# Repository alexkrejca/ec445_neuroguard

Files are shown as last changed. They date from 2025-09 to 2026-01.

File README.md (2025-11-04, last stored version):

# ec445_neuroguard
Repository for ECE 445 Senior Design Project, Neuroguard

# Lab Notebook
# 10/5

# 10/7
ESU Monitor V1
# 10/8
Using the ESU Monitor we created over the past couple days, we completed our first breadboard demo.

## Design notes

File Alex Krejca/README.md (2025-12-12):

# Alex Krejca
# Lab Notebook
# 9/16
First meeting with team members and TA to discuss the start of our project. Went over the general goals of the project and planned the first steps.
# 9/19
Researched ways to separate the project into different modules to complete. Determined separating the project by voltage level was a good way to start. Completed the project proposal, specifically worked on the problem, solution, and ethics and safety section.
# 9/22
Presented our project proposal to our TA Shiyuan Duan and Professor Yu.  The project was approved and both provided feedback.

# 9/24
Held a meeting with Meenakakshi Singhal, the main member of the Carle Medical Team we are working with. We received clarification on some of the specifications the device needs to adhere to. THe nerve stimulation waveform needs to be from 100Hz-1kHz that will only be ON when the ESU source is OFF, or cauterizing. The device needs to be powered from the wall or ESU source. Most likely,  we will work to power it from the ESU source.
# 9/27
Met with Stephen to go over the design of the low power stage. Put the circuit that was previously designed into LTSpice to see how it functions. Multiple issues in this circuit. Determined that this ESU monitor should be redesigned. 
# 9/29
This week, Stephen worked to hash out a starting ESU monitor design that can be implemented for the first breadboard demo next week. Provided updates on the design and reviewed the circuit in simulation to test the functionality. Some of the design calculations noted before, such as the input source voltage divider at the 2000V from the ESU.

**1. Capacitive Divider Ratio**
Ratio ≈ 10pF / (10pF + 3900pF) = 10 / 3910 ≈ 1/391 

**2. Voltage Scaling**
1850V / 391 ≈ 4.7V

**3. Frequency Period**
1 / 307kHz ≈ 3.26 µs

**4. RC Time Constant**
τ = R * C = 5,600 Ω * 0.000000001 F = 5.6 µs 

**5. Reference Voltage (Voltage Divider)**
V(ref) = 5V * (R3 / (R6 + R3)) ≈ 0.3V

These calculations are important as it reduces the voltage significantly.
# 10/6
Met with Stephen in the lab to assemble this first ESU monitor design from simulation. Parts were easily acquired using parts found in the lab and the ECE service shop.
# 10/7
Initial implementation problems occurred on this day. The main problem found was that the ESP32 works at a 3.3 V logic level. This meant we needed to make changes to some of our voltage divider calculations and acquire different parts from self-service to work at this voltage level. I will work to figure out a different solution to this problem after our first breadboard demo tomorrow.
https://learn.sparkfun.com/tutorials/esp32-thing-hookup-guide/hardware-overview 
# 10/8
Met with TA for our first breadboard demo, everything works successfully in our first design. This breadboard design is below.
Breadboard 1 Design: 
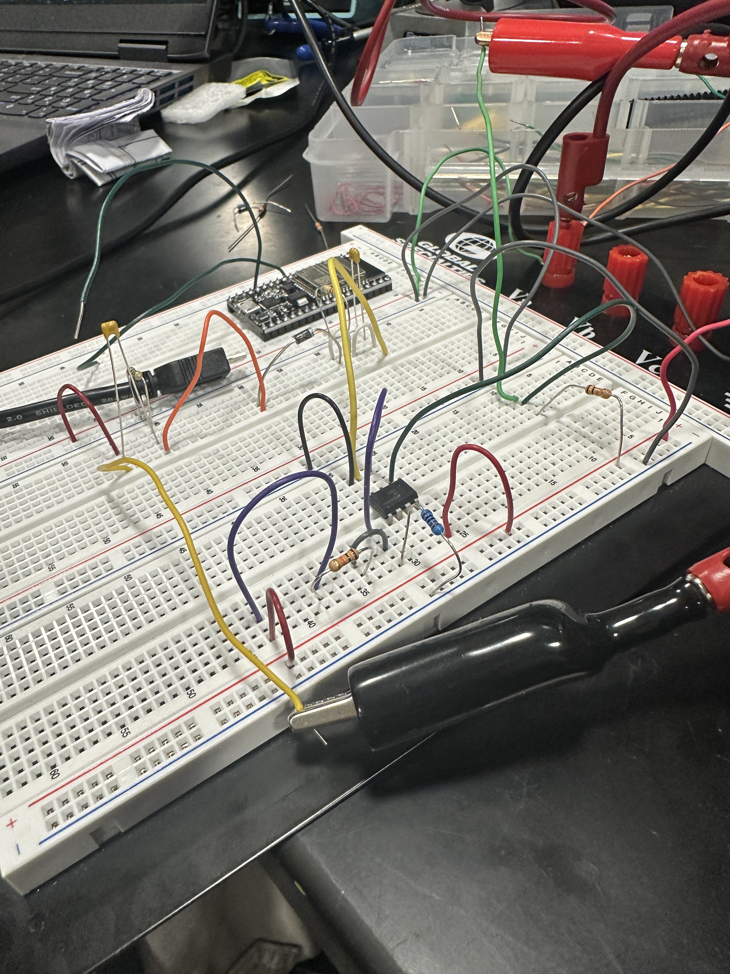
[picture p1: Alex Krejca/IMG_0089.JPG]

# 10/12
Timer was added to the ESU monitor to match the BOVIE specifications that were noted by the Carle Medical Team. This was done using a 555 Timer IC. 
# 10/13
Worked on finishing the design document while Stephen converted the LTSPice simulation onto a PCB in KiCAD before the order deadline on Thursday.
# 10/17
The Low Power PCB was ordered today due to the extension in the order deadline.
# 10/24
Met with Stephen in the lab to add changes made to the design onto the breadboard and adjusted the resistors for the 3.3V output ESP32.
# 10/28
Met with TA, 2nd breadboard demo went well, no issues. Waveform’s shown below.
Breadboard 2 Waveforms: 
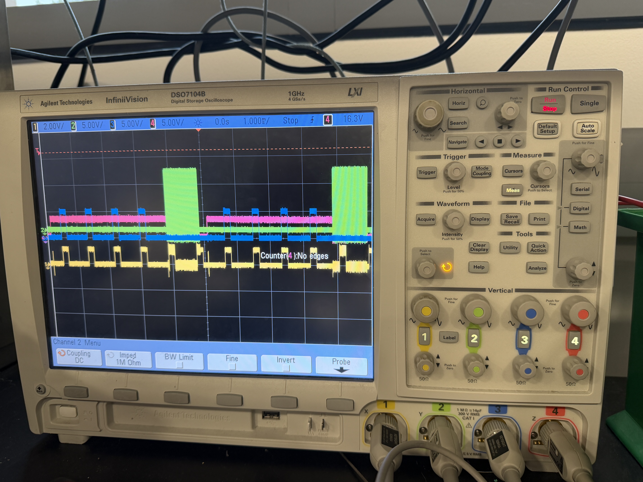
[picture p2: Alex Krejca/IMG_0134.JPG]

# 11/3
Not much happened this week, modifications made to the previous PCB submitted as it became clear we would be unable to test 2000 Volts in the lab. Stephen recommended we resubmit the PCB with a design for the lower voltage AC source that can be tested in lab so another PCB was ordered. 
# 11/18
TAs informed us the PCBs ordered from the previous order arrived, will go in the lab tomorrow to assemble the Low Power PCB. Aiden’s PCB has arrived and will be assembled over break before the final demo. 
# 11/19
Soldered the ESU Monitor part of the PCB, some soldering difficulties but this part appears to work in simulation.
# 11/20
Soldered the rest of the PCB board, but the microcontroller used, the ATTiny85, would not let us program, will figure this issue out tomorrow before Mock Demo hopefully. Detection issue so either a soldering issue or the cable to connect to computer may not be working as this can be a common issue.
# 11/21
Went to one of the TA office hours to exchange the adaptor cable, and this solved our issue.1 minor issue was the omission of a resistor that was included in our schematic but accidentally omitted in the PCB design. Went through each section of the low-power stage and ensured each part worked, everything locked good for the mock demo.
# 11/30
Coming back from fall break, Aiden had assembled the Mid Voltage stage the previous day so we could implement all the stages together. However, we ran into a significant problem, the microcontroller has completely stopped responding, most likely due to overvoltage being into the microcontroller when testing the mid voltage stage. Desoldered this broken ATTiny85 and replaced it with the spare we had. Thankfully, everything worked after it was replaced so we were ready for the demo tomorrow.
# 12/1
TA’s and professors overviewed our final demo, everything worked accurately. An image of the successful waveforms is shown below.
Final Waveforms:
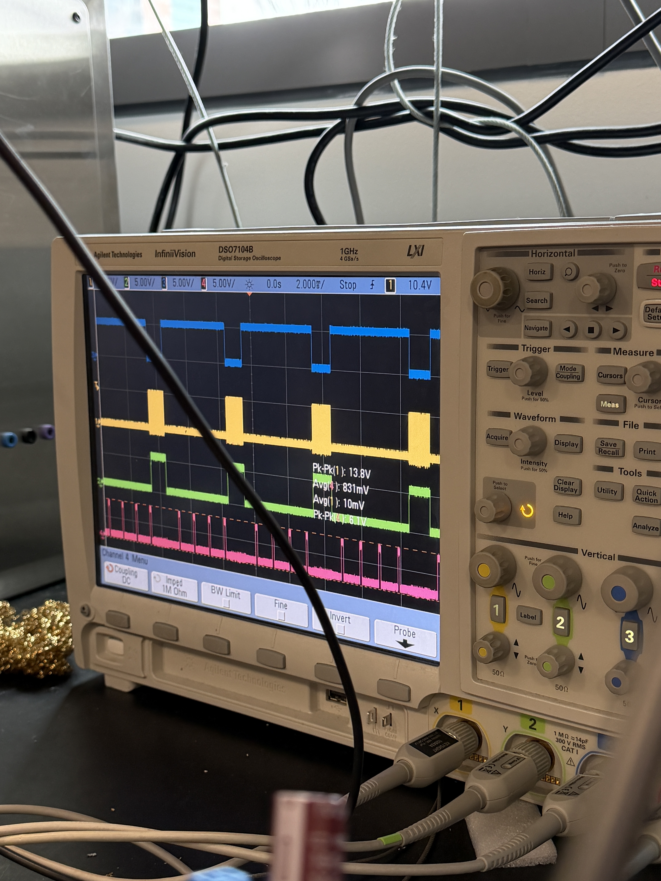
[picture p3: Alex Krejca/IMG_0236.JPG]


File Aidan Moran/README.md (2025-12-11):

# Aidan Moran ECE 445 Lab Notebook #
Fall 2025, Nuerogaurd, Team 31
All images, graphs, designs, etc. are in the documents folder

## 9/11
Initial meeting with nuerogaurd team. I selected this project as I felt the focus on power electronics and specifically buck converter design matched well with the courses I was taking (ECE 464) and previous internship experience. Main criteria for our scope of the project sounded like 
  - power supply to interface
  - creation of the nerve stimulation waveform
  - Unsure if we will have to do the signal prossesing and nerve detection as well.

Next Steps 
  - Reading literature
  - contact fellow nuerogaurd team members

## 9/16
Meeting with nuerogaurd members. We divided project scope and focus. I will be taking the power system (2kV DC step down to 5V DC) 
Next steps
  - reading literature on nerve stimulation, Electrosurgical Unites
  - Papers

N. D. Shilev and G. A. Konesky, “Multi-button electrosurgical apparatus,” U.S. Patent 9,326,810, May 3, 2016.

M. Singhal, K. Kiunga, N. Kelhofer, P. Dullur, N. Chigullapally, S. Pappu, and M. L. Oelze, “Expanding the Scope of Intraoperative Neuromonitoring with Nerve-Specific Stimulatory Waveform Design,” Carle Illinois College of Medicine and Department of Electrical and Computer Engineering, University of Illinois Urbana-Champaign, Urbana, IL, USA.
Chappell AG, Bai J, Yuksel S, Ellis MF. Post-Mastectomy Pain Syndrome: Defining Perioperative Etiologies to Guide New Methods of Prevention for Plastic Surgeons. WORLD JOURNAL OF PLASTIC SURGERY. 2020;

Chappell AG, Bai J, Yuksel S, Ellis MF. Post-Mastectomy Pain Syndrome: Defining Perioperative Etiologies to Guide New Methods of Prevention for Plastic Surgeons. WORLD JOURNAL OF PLASTIC SURGERY. 2020;9(3):247-253.

Coopey S, Keleher A, Daniele K, et al. Careful Where You Cut: Strategies for Successful Nerve-preserving Mastectomy. Plastic and reconstructive surgery Global open. 2024;12(5):e5817-e5817

## 9/23
Meeting with team to discuss block diagram 
- High voltage stage, must interface with the Electrosurgical Machine.
- Need considerations for isolation and safety,  IPC 2221-b specifies design clearances, creepage, and dialectic breakdown      for high voltage PCB designs
- Need to find resources on how to design high voltage PCB. look at requirements for different dialectrics, trace spacing,      specialized components, etc.
- Mid voltage stage - get AC input and step down to ~100V. Feel confident finding a buck converter and selecting LC components, filtering, etc to manage this.
- Find resources on noise tolerences for hospital applications, how much noise can be put back into the cauterizing machine without causing issues ?

## 9/29
Design buck converter for first round PCB orders october 8th. Selected the LM5186, 120Vin max, 300mA max output current wide Vin DC-DC converter. I feel one of the big difficulties for the project is the very unconventional nature of the design. It is high voltage, yet low power. Most reference design I have found are high voltage, and high power, which is not what we need. 

Design notes
Switching frequency selection
- need something fast to decrease L size, but not too fast there are timing issues in the design. Going from 100V - 5V will require a miniscule duty cycle of 0.05. Doing this on too high of a switch frequency means the switch will not be able to keep up
- Reference design suggests 750kHz, choose 750kHz. gives Rt = 33.2 k
  
  $$R_T = \frac{2500 \, V_{\text{OUT}}}{F_{\text{SW}}} \;\text{k}\Omega$$

Inductor selection
- need to size up the inducotr significantly, want very tight output tolerences. Any noise created by the buck converter will spread throughought the low voltage design, potentially interfering with the creation of nerve stimulatory waveforms

  $$L = \frac{(V_{\text{IN}} - V_{\text{OUT1}})}{K \, I_{\text{PRI}} \, F_{\text{SW}}}
\frac{V_{\text{OUT1}}}{V_{\text{IN}}}$$

selecting a value of 120 uH, sized up slightly from this equation. there is no consequence for using a larger inductor other than taking up more space on the PCB. Must manage space but I beleive this is worthwile tradeoff for the quality of the output. 

Sizing of Cout - again need larger Cout to minimize ripple, particularly from how extreme the Vin-Vout conversion is. 

$$C_{\text{OUT}} > \frac{\Delta I}{8 F_{\text{SW}} V_{\text{ripple}}}$$

$$\Delta I = \frac{(V_{\text{IN}} - V_{\text{OUT1}})}{L F_{\text{SW}}}
\frac{V_{\text{OUT1}}}{V_{\text{IN}}}$$

very interesting to the application of 464 content within this class. Inductor ripple current creates the output voltage ripple, want L and C as large as possible to reduce this, without sacrificing PCB sizing. Additionally adding 10n capacitors around this design to filter out high frequency noise, as this will also interfere with the output quality.

Feedback Resistors.

Working of reference as well. As this converter will not need to handle extreme transients (I think), there does not need to be capacitors in the feedback bath. 

$$R_{\text{FBT}} = R_{\text{FBB}} 
\left( \frac{V_{\text{OUT}}}{V_{\text{REF}}} - 1 \right)$$

Select RFBT as 198.6k, RFBB as 66.8k. Reference voltage is 1.8V 

Input capacitors

Adding them close to the Vin pin to reduce parasitic inductance in the input path/ voltage spikes. Large filtering capacitor from the full bridge rectifier AC/DC converter shouold take care of supplying most of the charge. Adding 10nF high frequency capacitors as well. 

Boost capacitor - use 2.2n
EN - dont think this design will need, Tie to Vin
PGND vs AGND - tie to one plane

Other considerations / need more research
- what transients will this design need to handle
- what filtering (EMI/EMC) to not disrupt other medical devices.
- Thermal considerations, low power but how do I simulate these. Do not want to order a PCB and find out it cannot handle the power present. Maybe look at increasing pour size, Vias, extra layers, ETC.

AC/DC converter
- use high frequency shotkey diodes for the full bridge rectifier
- oversize capacitor, with senior design funds and nuerogaurd funds I see no reason to not spend more for larger filter and thus better performance.

Design and simulation is looking good in PSpice for TI
- Input ripple - 0.8V at 100V AC sine inout 1000Hz
- Output ripple - 300 mV
  
## 10/5

PCB layout and design
Considerations
- keep SW node as small as possible
- HF filtering caps around the design
- keep feedback line away from switch node to not couple noise into the 

  Resources
  - Reference PCB design for LM5186
  - previous experience
    
## 10/10 
- prep for Design document, need to research more the high voltage system
- If we want the nuerogaurd to be purely powered by a high voltage source, how can we cantrol the high voltage inverter without a 5V dc/low level voltage supply already there. Would be easier to pivot to having an external power source for this.
- Look at self resonating oscillators/relaxation oscillators, probably the best idea as they do not require active control from low voltage logic and can self resonant from their LC/LCR constants

## 10/15
Email correspondance with proffesor Fliflet and professor Banerjee discussing options for high voltage measurements. A few key questions must be answered. 
- What equipment is available that can handle these measurements. Currently, students have acces to 1.5kV max differential probes in the power electronics labaratory.  However, we must engineer for worst case scenaries, not an ideal scenaria. Max open circuit output would be 3.9 kV. Is there any equipment that students have acces to that would allow for this measuremnt, ideally a probe rated for up to 5kV-6kV
- Alternative measurement options. Could we use a resistive load and current probe to get proxy measurements for voltage, in an inderect manner.
- SAFETY. How can this measurement be done safely, without risking harm to students. An electrocautyr machine is easily capable of damaging human flesh, and worst case scenario would be permenant damage to student, and potentially death. Are there high voltage encolsures, isolation mechanisms, and remote sensing we can implement to mititgate safety risks ?

  The outputs of the Bovie Electrosurgical generator are given below.

| Mode | Output Power | Output Frequency | Repetition Rate | Open Circuit Vpeak max | Crest Factor* (Rated Load) |
|---|---|---|---|---|---|
| Cut | 120 W @ 500 Ω | 357 kHz ± 50 kHz | N / A | 1250V | 2.9 ± 20% |
| Blend | 90 W @ 800 Ω | 357 kHz ± 50 kHz | 30 kHz ± 5 kHz | 1850V | 3.3 ± 20% |
| Coagulation| 80 W @ 1000 Ω | 475 kHz ± 19 kHz | 57 kHz ± 5 kHz | 3300V | 5.5 ± 20% |
| Fulguration| 40 W @ 1000 Ω | 410 kHz ± 50 kHz | 25 kHz ± 5 kHz | 3900V | 7.7 ± 20% |
| Bipolar | 30 W @ 200 Ω | 520 kHz (-14 kHz, +29 kHz) | 32 kHz ± 5 kHz | 1200V | 6.9 ± 20% |

\* an indication of a waveform's ability to coagulate bleeders without a cutting effect

Proffesors responded, requesting more data and research before this may get started. I believe a well thought out document outlining the details of this measurement will be sufficient to gain instructor approval. 

# 11/20 Meeting with Meenakshi at Carle Hospital Cardiovascular Center

Meeting with Meenakshi in the morning of November 20 to get a look at the Bovie Electrosurgical generator. While not a technical meeting, it was very inspring to see the depth and breadth of novel technologies being implemented in the medical space. I was able to visit their surgical training center and look at the Electrosurgical generator. It would have been helpful to be able to take it apart and atempt to reverse engineer the electronics present, However this was not possible given the price of these machines and the fair of permanently damaging its operatio.  

## 11/17
PCB has been delayed until after fall break

## 11/30

PCB construction session 
Parts and PCB have finally arrived, can now start assembly. Total assembly took about 3 hours. No issues with assembly.
During testing there was in issue with the vairac interfacing with the oscilliscope. When the probe was set to high Z input, with the mid voltage stage disconnected, It worked well and I could easily see a smooth sine wave from the variac, measured to be around 59.7 Hz. However when the device was connected, and I tried to turn on the variac, the variac would buzz loudly, and it would be difficult to turn, making me think there was some type of short circuit being created through the oscilliscope. When the device was connected, and there was no oscilliscope probe measuring the variac output, the device and variac worked as expected. After double checking the design and making sure all solder joints were done well and there was no possible short circuit from the Mid Voltage stage, I concluded that the oscilliscope probe must somehow be causing interference when connected to the output of the variac. 

The results of the mid voltage stage are as follows 

| Load | Output Voltage | Output Ripple | AC Input | Rectified DC | Rectified DC Ripple |
|---|---|---|---|---|---|
| 100mA | 5V | 288 mV  | 40V | 39.6V | 6.9V |
| 0mA | 5V | 1400 mV | 40V | 39.6V | 6.9V |

The full load ripple is slightly outside the ripple specified in the design document of 250mV. However I am confident that slightly increasing the output capacitance, say from 22uF to 27 uF, would cause a suitable drop in the output voltage ripple that would bring this design within specification. Again with the delays with the PCB we missed an entire round of prototyping and revision that would have allowed for these changes. 

Because of the soft start mechanism in the buck converter, I am not worried about start up transients corrupting the quality of the output voltage and damagin the low voltage analog circuitry for this device. Additionally, there are other safety mechanisms such as under voltage lockout and overvoltage protection to ensure that the device safely and reliably outputs 5V. 

### Testing integration with low voltage stage

Setup: Power supply used was a varaic. Input was 120V 60Hz, output was tested from 30V-60V AC at 60Hz. No visible issues with the power supply. No smoke, no parts felt excessively hot after testing. The power supply was ran continuously for around 20 minutes, and performad consisntently throughought this timeframe. The Input from the variac was rather noisy. However hoping this is not a pervasive issue as the output from the electrosurgical generator should be higher frequency, but also significantly less noisy. Again this is just a suspicion as we were unable to characterize the output of the ESU this semester, and I do not want to rely on such suspicion for design decisions. May be wise to add a lowpass EMI filter to the input of the buck converter in further design implementations

The low voltage PCB worked identically with the mid voltage stage power supply as with a benchtop DC power supply. All performance waveforms of the low voltage PCB were verified, and we are confident that it would then work during our demo tommorow. 

## 12/01
Demo went well. Proffesor Yu seemed satisfied with the quality of our demonstration, and meeting all demonstration criteria. He however, hinted that the scope of our project may have been too easy. 

## 12/02
With the senior design demo being completed, this concludes the technical development for this project 

# END OF LAB NOTEBOOK

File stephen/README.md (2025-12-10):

# Stephen Simberg
# Lab Notebook

# 9/24
Held a meeting with the lead on the medical team for NeuroGuard,
received clarification on what we are building:
A nerve stimulation waveform from 100Hz-1kHz that only is ON during the OFF cycle of ESU source. Power needs to be from wall (plug in)
or directly from ESU source.

# 9/29
First Design of ECU Monitor in LTSpice has been created.
Simulation Screenshot shown in ECUMonitor folder.  
2000V AC Source Capacitance Voltage Divider:  
```text
Ratio ≈ 10pF / (10pF + 3900pF) = 10 / 3910 ≈ 1/391 

This reduces the peak voltage from 1850V down to a much safer level: 
1850V / 391 ≈ 4.7V

▪ 1 / 307kHz ≈ 3.26 µs
▪ τ = R * C = 5,600 Ω * 0.000000001 F = 5.6 µs 
▪ V(ref) = 5V * (R3 / (R6 + R3)) ≈ 0.3V
```
# 10/6
All parts received for beginning to assemble first design of ESU Monitor, incuding ad dev board ESP32, comparator, resistors.

# 10/7
Found that the ESP32 only accepts 3.3V into dev board. This required picking up new resistors from self-service to output 3.3V 
where-ever we were outputting/receiving 5V. This is temporary for
bread-board demos of ESU Monitor.
# 10/8
First breadboard completed, screenshots in ESU Monitor folder. Everything went smoothly.

# 10/14
Created Timer IC circuit output at 1kHz and 100 us high, and integrated with ESU monitor circuit, uploaded LTSpice in ESU_MONITOR_V2 folder.  
**555 Timer High/Low Calculations:**

$$ T_{high} = 0.693 \times R_a \times C $$
$$ T_{high} = 0.693 \times 15,000 \Omega \times 0.00000001 F $$
$$ T_{high} = 100 \mu s $$

$$ T_{low} = 0.693 \times R_b \times C $$
$$ T_{low} = 0.693 \times 130,000 \Omega \times 0.00000001 F $$
$$ T_{low} = 900 \mu s $$
# 10/16
Designed first low-power PCB v1. Realized had issue with noise in output of cicuit when using actual components instead of the default LTSpice ones. Fixed this by adding a comparator output at end to filter out the noise and put a voltage divider to output 100mV from the 5V output of the comparator with the same nerve stimulation waveform as previous without any noise.

# 10/17
Low Power PCB has been ordered and approved by PCBway.

# 10/24
Designed 2nd BreadBoard of Low Power circuit. Changed out resistors to work with 3.3V ESP32.

# 10/28
2nd BreadBoard Demo was successful, images in ESU_monitor_V2 folder.

# 11/1 
Noise isolation added in first PCB required for 2kV filtering and dividing to 5V AC signal is not able to be tested in ECE 445 lab, so desigined a PCB_stripped. This takes as input a max 25V AC signal from waveform generator that acts as ESU source without actually being 2kV. This involved changing 2 Capacitors in voltage divider to 1, same exact characteristics displayed.
Ordered this PCB as well.

# 11/18 
PCBs ordered have finally arrived, picked up, verified look good.

# 11/19
ESU Monitor part of PCB built, same characteristics as in simulation shown on breadboard.

# 11/20
All parts of PCB have been soldered on, having issue programming micorcontroller, cannot detect device from programmer.

# 11/21
Received a new USart to USB-A adaptor, and that worked! Successfully ran end-to-end test of low-power PCB. Had to add 
1kOhm resistor to back of PCB, as forgot to add it in the schematic.

# 11/30
Added High Voltage Power component as input to low power PCB 5V source, and everything worked. 

Had to replace ATTiny85 with a spare because it stopped reposonding, possibly due to wrong output selected from DC Power Supply during testing. After replacement everything again ran smoothly.

# 12/1
Successful final demo, images attached.

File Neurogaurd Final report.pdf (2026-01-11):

# Neuroguard: A Dual Electrocautery-Nerve Monitoring Device to Prevent Injury During Mastectomy

By,

Aidan Moran

Alex Krejca

Stephen Simberg

Final Report for ECE 445, Senior Design, Fall 2025

TA: Shiyuan Duan

10 December 2025

Project No. 31

### Abstract

Post-mastectomy pain is a common element of the patient experience in the weeks and months following surgery. The majority of cases have been attributed to transection of the intercostobrachial nerve (ICBN), a cutaneous nerve that provides sensation to the chest wall and upper arm. With reconstructive surgeries and allografts posing their own set of potential complications, exploring avenues for preventing nerve injury within the operating room can pave the way for safer procedures that maximize patient outcomes. By redesigning the way a standard electrosurgical unit (ESU) delivers energy to tissue, we propose a novel tool for intraoperative neuromonitoring (IONM) that can be integrated within existing surgical workflows. This work is a proof of concept for the hardware platform, demonstrating the capability to integrate power conversion and waveform generation that could be implemented with a standard cautery probe.

iii

### Contents

iii

### 1. Introduction

Over 100,000 mastectomies are performed yearly in the U.S., with 40-60% resulting in nerve injury that can lead to a variety of symptoms, notably post-surgical pain [1]. In particular, damage to the intercostobrachial nerve (ICBN) is common during mastectomy and axillary lymph node dissection, a set of procedures common in treating metastatic breast cancer. Recently, surgeons have begun utilizing nerve-sparing techniques to ensure greater patient quality of life; however, these innovative techniques require meticulous dissection that can be complicated by anatomical variation and intraoperative bleeding.This highlights an urgent need for a device that provides real-time feedback to surgeons, enhancing safety and precision while also being easily integrated into existing workflows. To address this problem, we propose NeuroGuard, a device designed to alert surgeons when they are approaching the ICBN nerve during operations, thereby reducing nerve injury rates and improving patient outcomes.

Inspired by recent multifunctional surgical devices like a dual monopolar probe and suction tool, we are working with the NeuroGuard team to integrate contactless nerve detection and cautery functionalities into a single, cost-effective device. Over the course of the semester, we will work to design and simulate a circuit that demonstrates the ability to switch between predefined electrocautery and nerve stimulation waveforms at specified time intervals. We will work to prototype this circuit that can be integrated with an electrosurgical unit and standard monopolar electrocautery probe. This project is a proof of concept for the hardware platform, demonstrating the capability to integrate power conversion and waveform generation that could be used with a standard cautery probe. The scope is strictly limited to the development and testing of this hardware; the detection of neural activation and the development of a feedback mechanism are considered future work beyond the scope of this project.

### 2 Design Overview

The design of the neuroguard must satisfy a few key objectives. Power supply integration with the output of an Electrosurgical Unit (ESU), detection of the ESU operation state, and creation of suitable nervous stimulatory waveforms. This nerve stimulation waveform is sent out as a pulse signal during the OFF portion of the duty cycle of the electrocautery AC source and Neuroguard is powered by this same source. The specifications of what the nerve stimulation signal should be, and the input source were specified by the medical team [3], and the actual detection of nerves using this circuit is a next step outside the scope of this project. The block diagram in Figure 1 shows each section of the design and how they connect together.

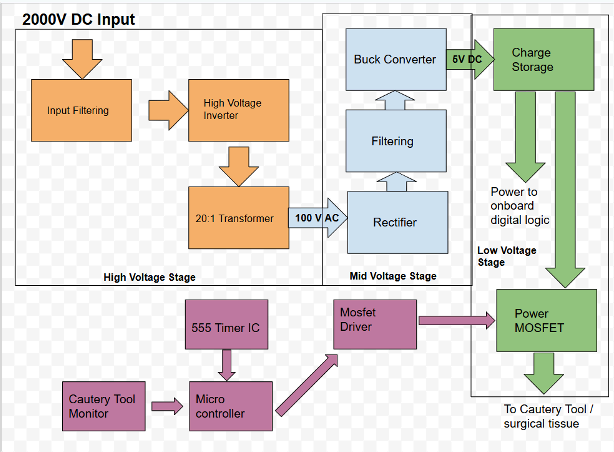
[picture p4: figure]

Figure 1: Block Diagram for Design

### 2.1 Power System

One of the key aspirations, and challenges, of the neuroguard, is to be able to integrate directly with the output of an ESU. This includes being able to power the device directly from the output of the ESU. The reason for this is to increase ease of use for practitioners, allowing for one apparatus that can connect in between the ESU output and cautery pen. Additionally, having a separate power supply for the device would make it more expensive and regulatorally complicated, hindering the use and uptake of the device. The power system of neuroguard must therefore be able to use the output of an ESU, and safely step down the device to 5V, for use in the low voltage circuitry and creation of suitable nervous-stimulatory waveforms.

### 2.1.1 High Voltage

One of the key challenges for this design project was the high voltage work. The Bovie Electrosurgical Generator, the cautery machine that the neuroguard is being designed for, produces maximum open circuit voltages in monopolar mode between 1250V- 3900V [2], with peak voltages being even higher The differential oscilloscope probes, which are the highest rated voltage measurement equipment that students have access to, has a maximum voltage of 1500 V. This makes it difficult to even get a measurement of the output in the first place without risking damage to expensive school equipment. School research labs have equipment rated for higher voltages, but these require tedious logistical setups and consent from the supervising professor. Additionally, safety concerns are at the paramount of this course. An output of 1500V at 70W is easily capable of causing permanent injury and death to students. Because of all these concerns, ultimately high voltage work fell out of the scope of the project for this semester.

Nonetheless, through the research we have done this semester, we have proposed a design to be tested by the neuroguard team that allows for the implementation of a high voltage power source from the ESU. From reading the Bovie Electrosurgical Generator patent, it was noted that when not operating, the device outputs a ‘quiescent voltage’ across its monopolar outputs. This voltage could be used by the neuroguard to draw power from the ESU when the device is off, through a step down transformer. When the neuroguard detects that the ESU is on and outputting a higher voltage cutting or coagulating waveform, the power supply would use a high voltage e-fuse to disconnect itself from the output, in order to prevent interfering with the surgical operation of the ESU. Again full measurements and characterization of the ESU output are needed to begin formal design, construction, and testing of this proposal.

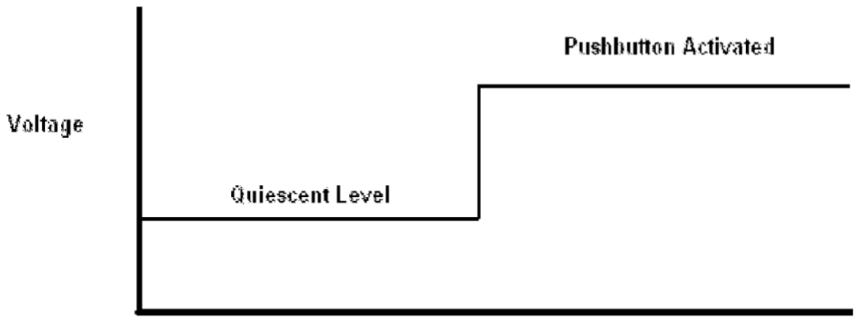
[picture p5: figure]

Figure 2: Simplified diagram of Bovie Electrosurgical Generator output waveform, clearly identifying a lower quiescent voltage when the device is off.

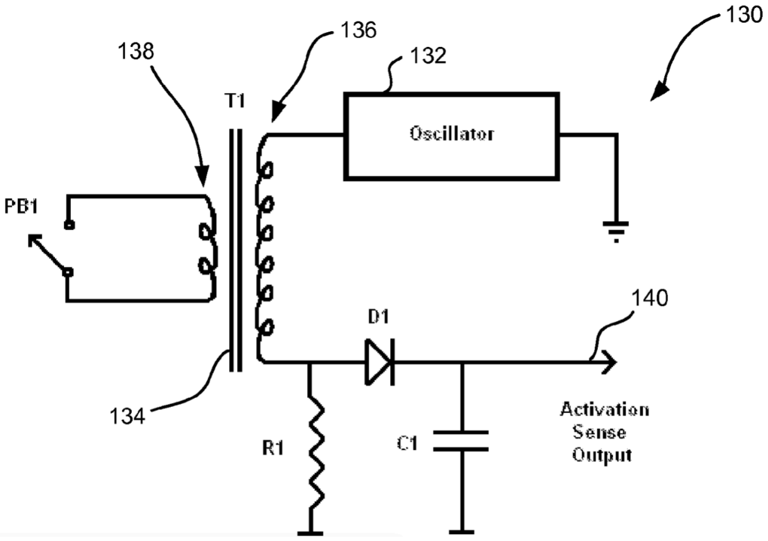
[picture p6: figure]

Figure 3: Simplified output diagram of Bovie Electrosurgical Unit

### 2.1.2 Mid Voltage

The mid voltage stage is responsible for taking high voltage AC input (80V-100V) at high frequencies of 50kHz to 100kHz, and stepping this down to a 5V DC output, within acceptable ripple tolerances. This is achieved via a full bridge rectifier using four 200V 400mA fast recovery shotkey diodes and a 100μF 160V output filter capacitor. This is then fed into the heart of the system, an LM5168 120V wide input voltage synchronous buck converter. This steps the input voltage down to 5V, and provides the line and load regulation for the output. The Schematic and PCB layout are given in appendix B.

The Mid Voltage stage has a few key subsystems that ensure correct operation. The Full bridge rectifier composed of diodes D1,D2,D3,D4, and input screw terminal J1 connect to the input from a stepped down waveform from the ESU (nominally 100V AC, 50kHz - 100kHz). This stage converts the input into pulsed DC. The capacitor bank composed of CFB, CIN1, CIN2, CFILT3, and CFILT 4 serves a variety of functions for the device. CFB is a large capacitor that is designed to smooth the pulsed AC into low ripple DC. CIN1 and CIN2 provide charge storage for the pulsed current demands of the buck converter. CFILT3 and CFILT4 are 10nF each, and provide a low impedance path for high frequency noise, to prevent it from propagating through the device and disrupting operation. At the heart of the design is the LM5168 buck converter (U1). The output filters of L and C were calculated using these formulas [3].

L = | (2.1)

(V

in− V
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
C > | (2.2)

∆i
L
8·F
SW

·∆v
O
∆i | (2.3)

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
Where, K is the desired ripple factor, which was selected to be 0.2 to minimize inductor current ripple, and thus output voltage ripple.The output voltage ripple, ∆v , was desired to be less than 5% of output,
O
which limits output voltage ripple to 250mV. From these equations, the inductor value was chosen to be 120μH, and the output filtering capacitor COUT1 was chosen to be 22μF, which is a standard package size. Additionally CFILT1 and CFILT2, both 10nF, were added to the output to further filter high frequency noise. The switching frequency of the converter was a critical decision, as this would determine the sizing of the output inductor and capacitor. As the duty cycle on this converter is very low, the switching frequency may not be too fast as to be limited by the MOSFET turn on and turn off time. At the same time, a slow switching frequency requires larger Inductors and capacitors to achieve the same output ripple, thus increasing the boards size, and component cost. Per recommendations in the datasheet, the switching frequency was set to 750 kHz. Other components, such as feedback resistors and enable resistors were sized appropriately using relatively trivial equations found in the LM5168 datasheet [3].

On the PCB, a few key design decisions are important to note. Due to the high current transients present in the buck converter, all traces supplying power to and from the buck converter are needed to be kept as short as possible. Additionally, the high frequency filtering capacitors must be placed as close as possible to the input and outputs of the devices, seen with CFILT3 and CFILT4 being extremely close to the Vin pad of the LM5168. Again this is to reduce the parasitic inductances created by the PCB traces. Additionally, the switch node pad is incredibly noisy, due to the switching nature of buck converters, and must be a reasonable distance away from the feedback line to ensure safe operation. To add additional shielding to the feedback line, a ground pad has been strategically placed in between the switch node and feedback trace. Vias have been placed around the buck converter to aid with thermal dissipation and noise shielding. All power traces have been increased to 40 mil,to decrease DC resistance and provide better thermal performance. Much of the PCB criteria was guided by IPC-2221A criteria [4] After performing well in simulation, as seen in Figure 4, this design was released to manufacturing.

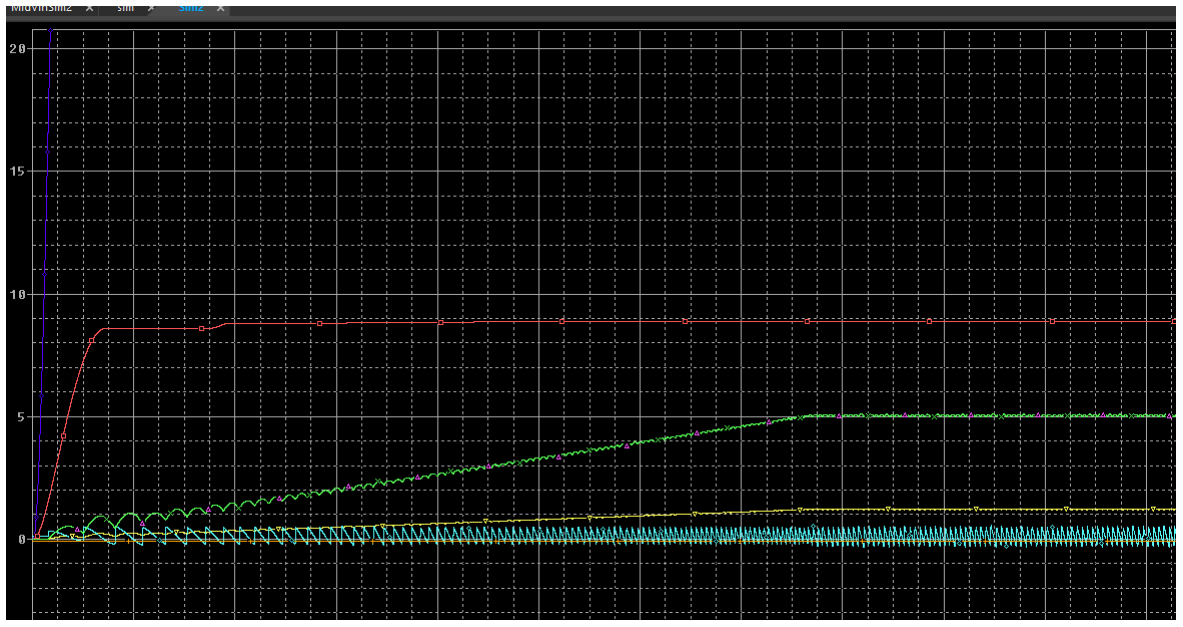
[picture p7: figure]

Figure 4: PSpice simulation of Mid Voltage stage, confirming behavior. Traces are as follows: Blue, VIn Red, Enable, Green, VOut

, Yellow, Feedback, and Cyan, Inductor current

### 2.2 Low Voltage Signal Processing and Waveform Generation

### 2.2.1 Cautery Tool Monitor

To create the cautery tool monitor, carrier AC source generates a high-frequency sine wave at a 925 V amplitude and 925 DC offset, with the frequency set to 307 kHz. This directly matches the specifications in the BOVIE cautery manual [2] the medical team had us use as reference. This design was tested with an ON cycle of 1 ms and OFF for 4 ms, and an ON cycle of 19 µs and OFF for 19 µs using a wave generator to simulate the BOVIE source repetition documentation. Components C1 (10 pF), and C2 (3.9 nF) are used to create the capacitance voltage divider. This is because at high frequencies, like the 307 kHz, capacitors have an impedance, and they divide AC voltage just like resistors divide DC voltage. A 10 kΩ resistor is also used to provide a DC path to ground so the output signal is not “floating”. Also, this resistor is large enough to have no impact on the AC signal division, as 133 Ω is much less than the 10 kΩ . The voltage divider with the 2000 V AC source is shown in Figure 5.

Capacitive Resistance: Xc = | (2.3)

1
2∗π∗f∗C =

1
2∗π∗307,000∗3.9∗10

−9 = 133 Ω

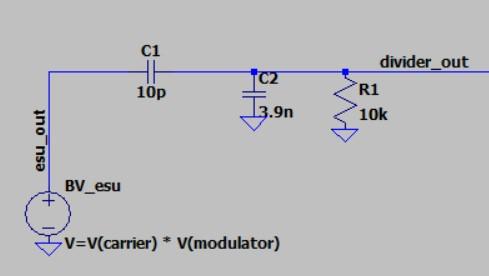
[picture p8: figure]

Figure 5: 2000V AC Source Capacitance Voltage Divider

Ratio = | (2.4)

10pF
10pF+3900pF =

10
3910 =

1
391
Peak Voltage Reduction: 1850V ∗ Ratio = 1850 ÷ 391 = 4. 7 V | (2.5)

A 2.2 nF capacitor is used when the input signal is much lower in voltage, and because of the same
high frequency signal used, has the exact same output as the capacitance voltage divider above. This design is shown in Figure 6.

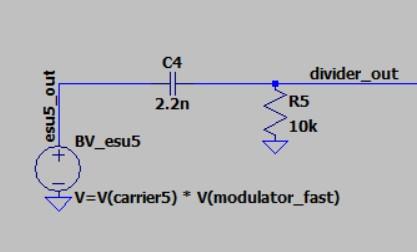
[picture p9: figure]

Figure 6: 5-20V AC Source

The next step is envelope detection which is used to output detect when the AC signal is ON vs OFF. This is fed into a comparator to output 5V when the AC signal is ON and 0V when the AC signal is OFF. The components used for this part are D1 (1N5817), R2 (5.6 kΩ), and C3 (1 nF). The diode D1 acts as a half-wave rectifier, allowing current to pass only on the positive peaks of the signal, which charges capacitor C3. When the carrier signal stops, D1 stops conducting, and C3 slowly discharges through R2. The result at the envelope node is a DC-like voltage that rises when the signal is present and falls when it's absent.

(2.6)

1
307kHz ≈ 3. 26µs
τ = R * C = 5, 600 Ω * 0. 001 µF = 5. 6 µs | (2.7)

The 5.6 µs time constant is long enough that C3 doesn't discharge too much between the 307 kHz peaks, preventing excessive ripple. Also, 5.6 µs must be shorter than the "off" time, where it is for both the 19 µs and 2 ms OFF cycles signals. The 1N5817 is a Schottky diode, It is used for its low forward voltage drop (so it can efficiently rectify even small signals) and its fast switching speed, which is necessary to handle the 307 kHz frequency.

The other components used in this part are U1 (LM393A), R6 (47kΩ), R3 (3kΩ), R4 (10kΩ). The comparator U1 (LM393A), compares the envelope voltage (on its positive input) to a fixed reference voltage (on its negative input). If Venvelope > Vreference

, the output goes HIGH. If Venvelope < Vreference

| , the
output goes LOW. The envelope detector and comparator is shown in Figure 7.
V | (2.8)

reference = 5V ∗ (

R3
R6+R3

) ≈ 0. 3V

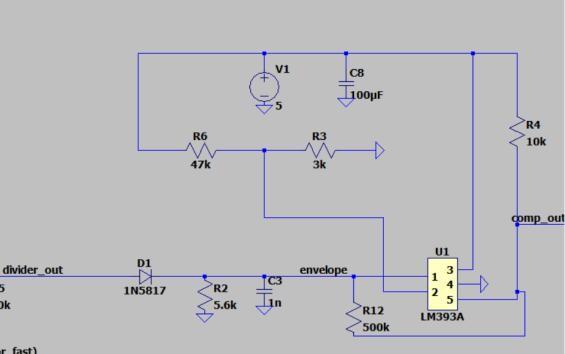
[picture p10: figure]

Figure 7: Envelope Detector & Comparator

This 0.3 V threshold is low enough to be reliably triggered by the envelope detector but high enough to ignore any small noise when the signal is off. The LM393 has an "open-collector" output, meaning it can only pull the output down to ground. R4 is used as a pull-up resistor for the comparator. When the comparator's output is "high" (inactive), this resistor pulls the comp_out voltage up to the 3.3 V supply rail as needed. 10 kΩ is a standard value that works well in most (including this) digital logic applications.

The entire design for the ESU Monitor circuit is shown below in Figure 8.

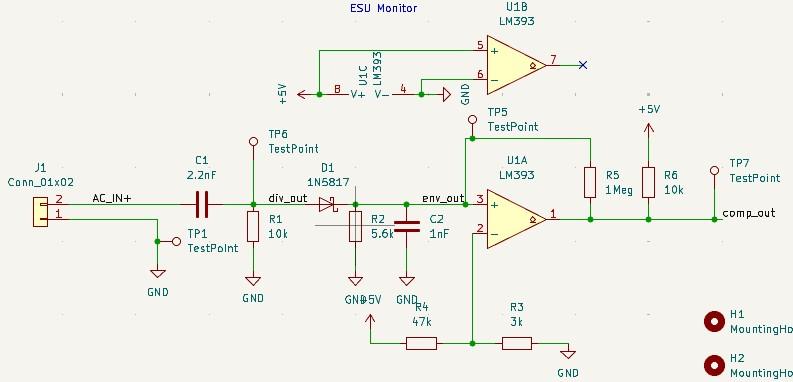
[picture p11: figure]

Figure 8: ESU Monitor Circuit

### 2.2.2 Microcontroller

The ATtiny85 microcontroller is used with a programmer to detect the Duty cycle of the AC signal and output 5 V on the off portions of the signal. Comp_out, the output of the cautery tool monitor, feeds into pin3 and the output on pin4. The schematic of the microcontroller portion of the design is in Figure 9.

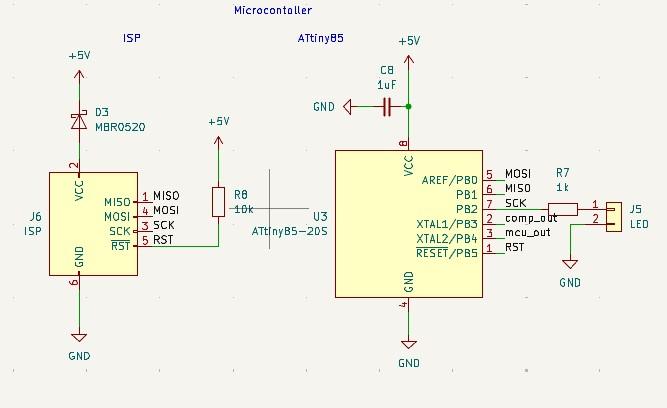
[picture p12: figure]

Figure 9: Microcontroller Schematic

### 2.2.3 Pulse Generator

The entire nerve stimulation output needs to be 50 Hz - 1 kHz with a Pulse width of 100 µs - 1 ms at 0.1 V [3], whose specifications were given by the medical team. In order to generate a pulse that fits the frequency and pulse width requirements, a N555 timer is used. With the discharge transistor off, the timing capacitor, C9 (0.01 µF), begins to charge through the timing resistors, R9 (15 kΩ) and R10 (130 kΩ). A diode is also used to time high, where it acts as an open circuit, and time low, where it acts as a closed circuit. Both of these formulas are calculated below. The duration of the output pulse is determined by the time it takes for the voltage across C9 to reach two-thirds of the supply voltage. This voltage is monitored by the timer's threshold pin (pin 6).

T | (2.9)

ℎigℎ = 0. 693 · R
a
- C = 0. 693 · 15, 000 Ω · 10⁻⁸ F = 1. 04 × 10⁻⁴ s = 100 μs
T | (2.10)

low = 0. 693 · R
b
- C = 0. 693 · 130, 000 Ω · 10⁻⁸ F = 9. 01 × 10⁻⁴ s = 900 μs

This creates a pulse signal of 1 kHz with a pulse width of 100 µs, which is what we need from the medical team specifications. The output voltage is 3.3-3.5 V when high, as there is a voltage drop of 1.5-1.7 V caused by the timer’s internal circuitry. The circuit diagram of the pulse generator is shown below in Figure 10.

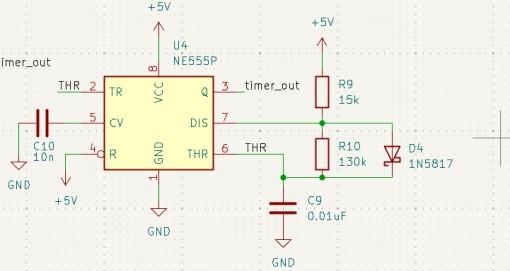
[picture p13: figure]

Figure 10: Timer Circuit Schematic

### 2.2.4 Neurostimulation Output

For the neurostimulation output, the Mosfet acts as the gate, where the mcu_out is the gate driver and the pulse as the source. This outputs the nerve stimulation waveform when both the mcu_out and pulse signal is high. This creates a 5 V DC signal of 1 kHz with a pulse width of 100 µs. However this signal has a lot of noise, which needs to be scrubbed away.

The last portion of the circuit designed is the output. This uses a LM393 comparator with the
reference voltage of 1 V (through a voltage divider of 5 kΩ and 1 kΩ), and the positive being the drain of the mosfet above, which when high is 3.3-3.5 V, higher than the 1 V reference as needed. A diode is also used to prevent noise in the output from the mosfet (acts as an open circuit in the direction from drain to gnd). This outputs a steady, noise free 5 V when input is above 1 V, which the drain of the mosfet will be when both the mcu_out and pulse signal is high. Lastly a voltage divider is used to output a 0.1 V signal of 520 Hz with a pulse width of 1 ms, which is well within the specifications of the neurostimulation output.

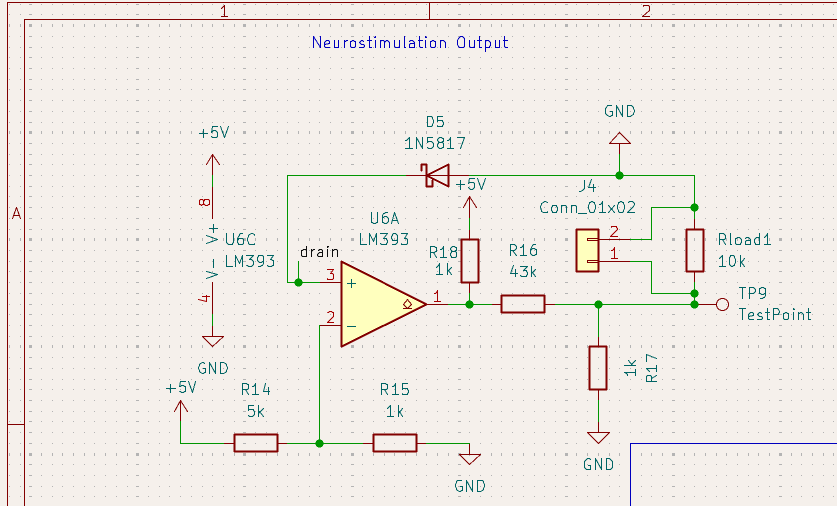
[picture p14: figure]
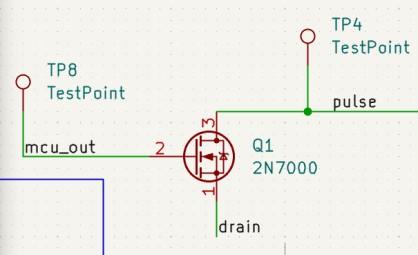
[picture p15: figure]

Figure 11 & 12: Mosfet & Neurostimulation Output Comparator Circuit Schematic

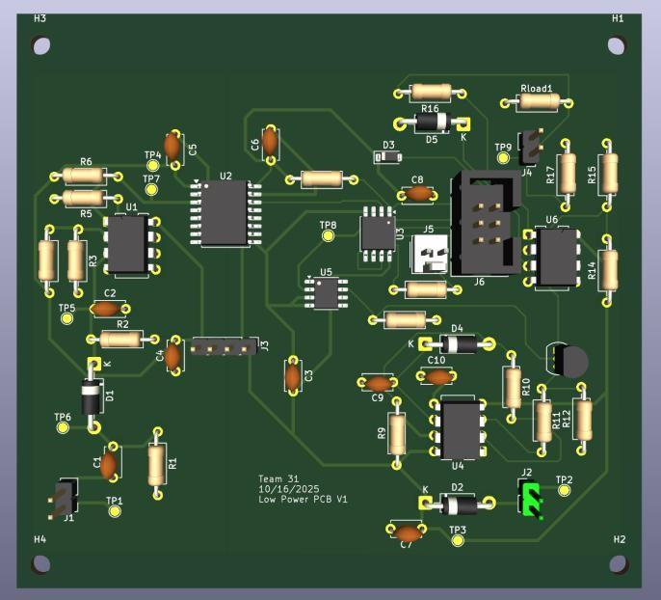
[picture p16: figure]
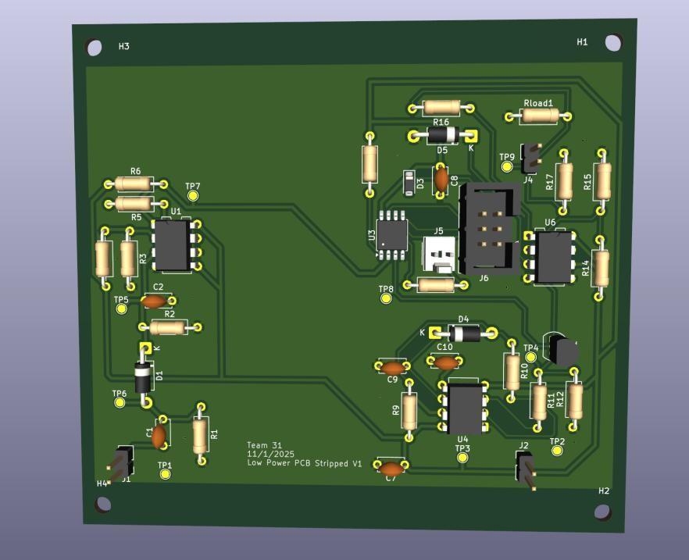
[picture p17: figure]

Figure 13 & 14: 3D rendering of Low Power PCB with Voltage Isolation & Low Power PCB without Voltage Isolation

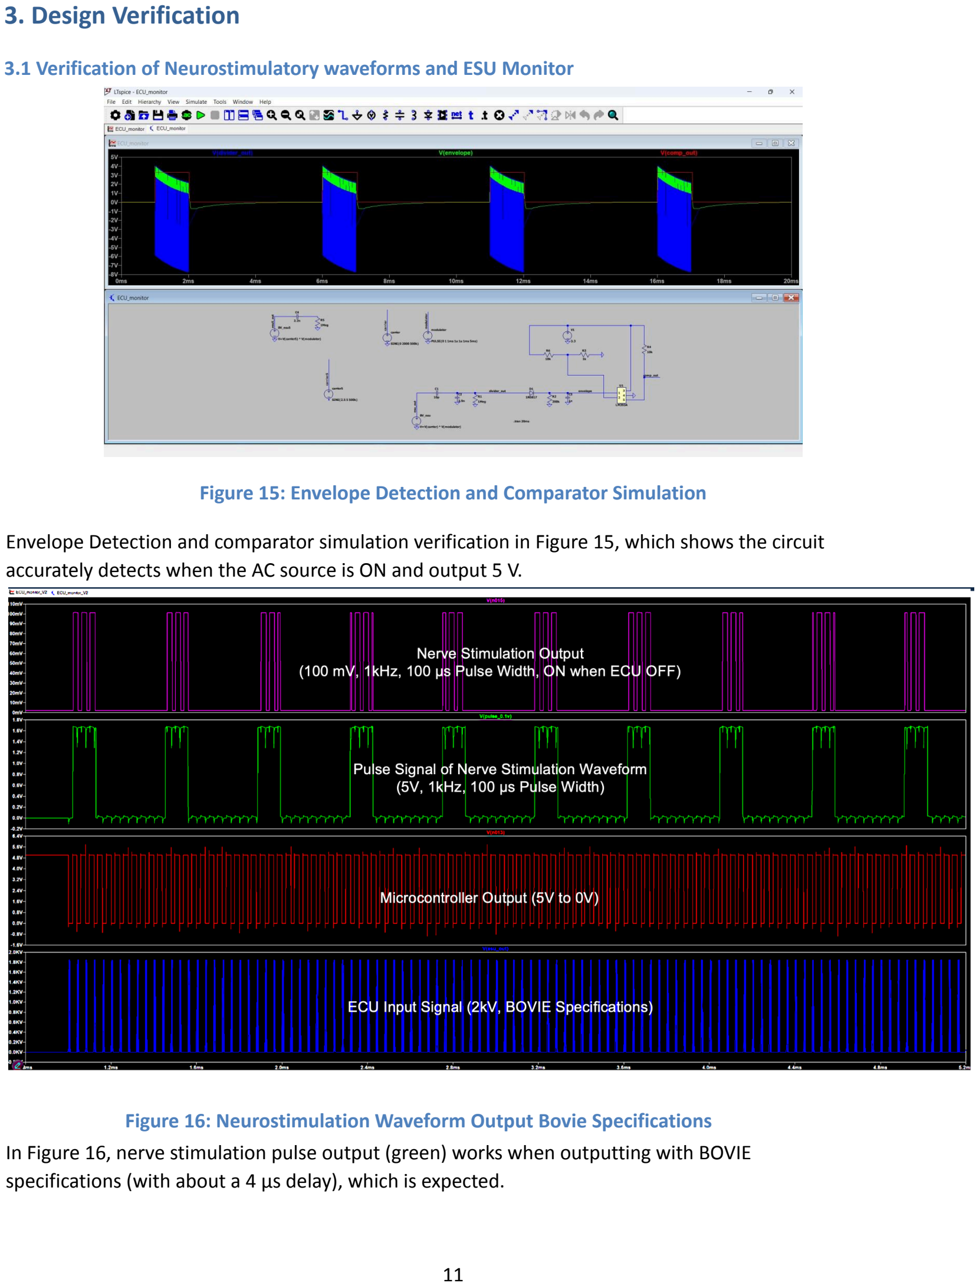
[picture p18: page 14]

### 3. Design Verification

### 3.1 Verification of Neurostimulatory waveforms and ESU Monitor

Figure 15: Envelope Detection and Comparator Simulation

Envelope Detection and comparator simulation verification in Figure 15, which shows the circuit accurately detects when the AC source is ON and output 5 V.

Figure 16: Neurostimulation Waveform Output Bovie Specifications In Figure 16, nerve stimulation pulse output (green) works when outputting with BOVIE specifications (with about a 4 µs delay), which is expected.

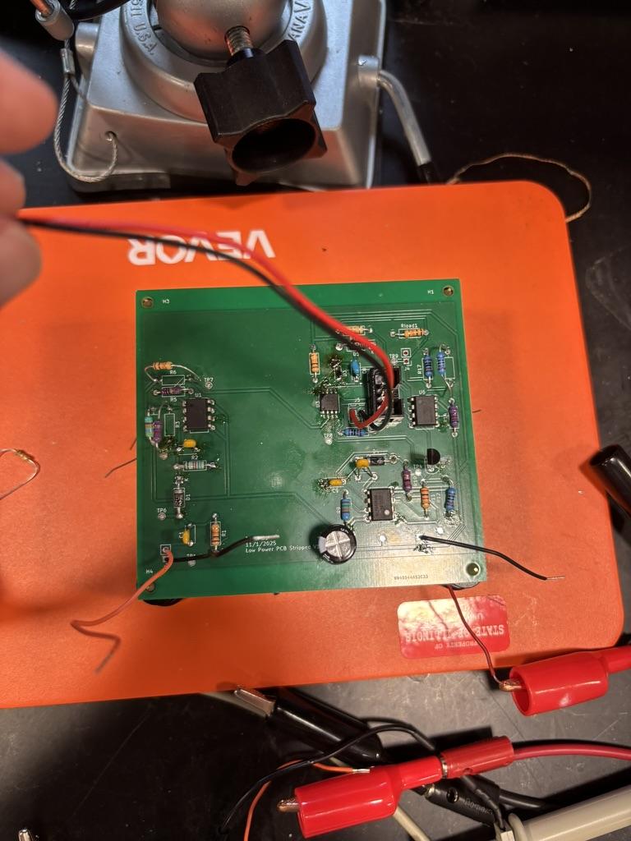
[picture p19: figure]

Figure 17: Completed nerve stimulatory waveform generation PCB

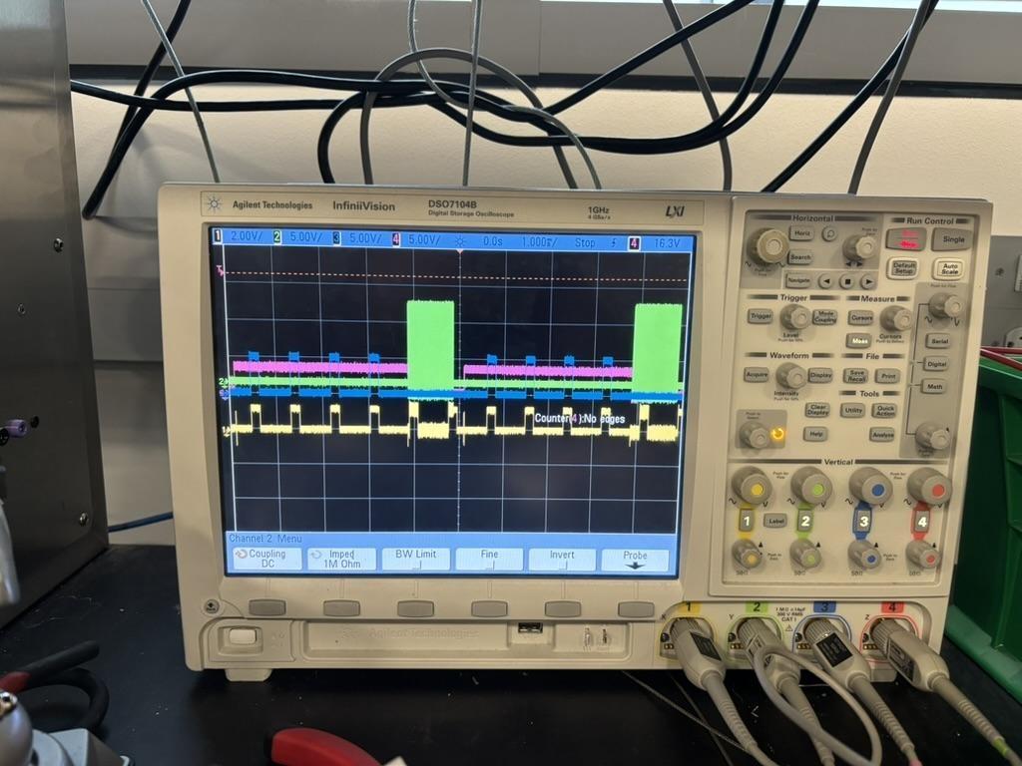
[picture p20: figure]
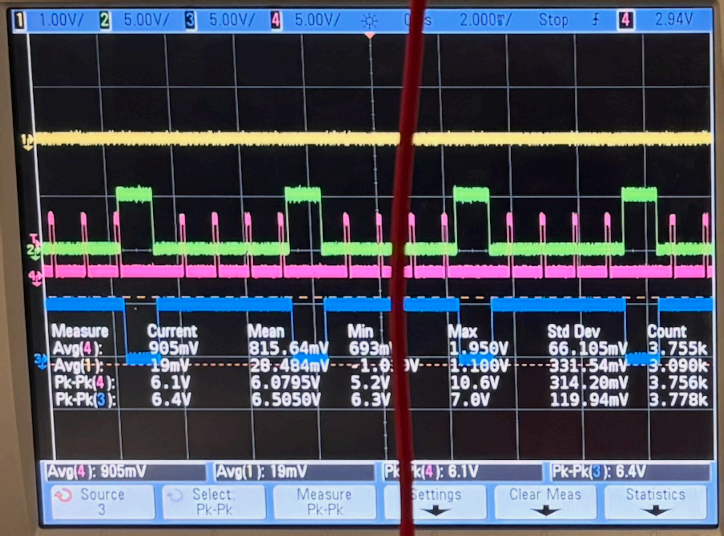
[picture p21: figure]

Figure 18 & 19: Final PCB Output The Figure 16 oscilloscope the output of the microcontroller (pink left, blue right) accurately detects when the AC signal (green) is ON. This breadboard design of the circuit above also shows the output pulse signal(blue left, pink right) is within what the specs should be, and the mosfet/comparator is accurately working to only output high (5V) when both the microcontroller output and pulse signal is high, which it is. All voltages are within the 0.5V tolerance described in the design report.

### 3.2 Verification of Mid Voltage Stage

After being constructed, the Mid Voltage stage was verified through oscilloscope measurements of the output, of both the 5V DC output and rectified AC input to the buck converter. A variac providing variable 60Hz AC sine wave was used as the input to the device. The results are as follows.

Table 1: Verification of Mid Voltage Stage

Load | Output Voltage | Output Ripple | AC Input | Rectified DC | Rectified DC Ripple
100mA | 5V | 288 mV | 40V | 39.6V | 6.9V
0mA | 5V | 1400mV | 40V | 39.6V | 6.9V

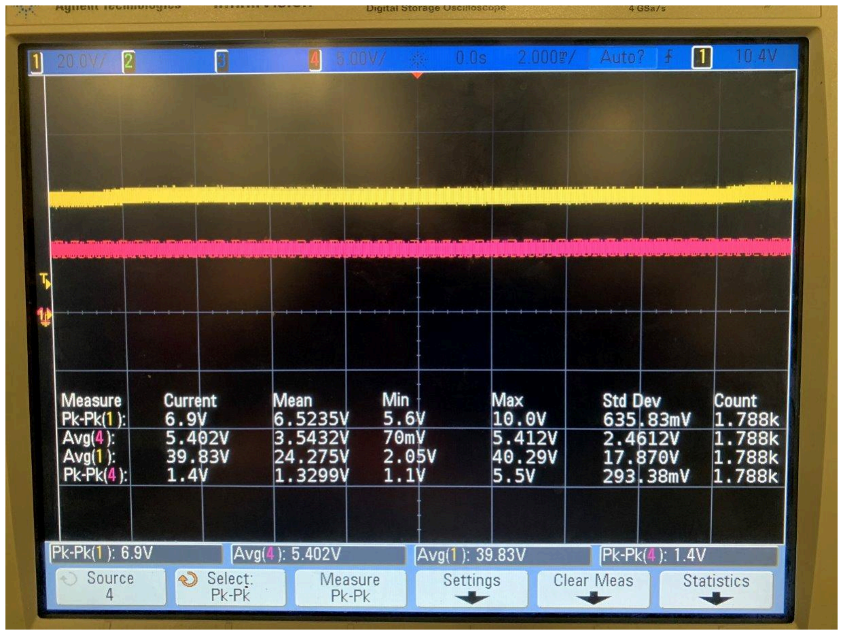
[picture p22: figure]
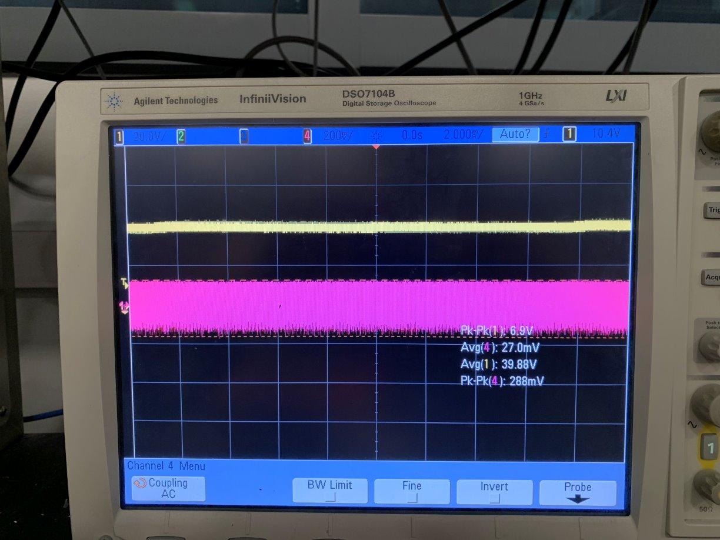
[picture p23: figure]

Figure 20 & 21: Oscilloscope Measurements of Mid Voltage Stage with No Load (right) and Full Load (100mA, left)

## 4. Costs

### 4.1 Parts

Table 2: Parts Costs For Mid Voltage Stage
Part Number | Manufacturer | Retail Cost ($) | Bulk Purchase Cost (1k units) ($) | Actual Cost ($)
BAV21W-7-F | Diodes Incorporated | 0.10 | 0.039 | 0.40
OSTTC022162 | On Shore Technology | 0.57 | 0.2248 | 1.14
EKMQ16ELL101MK25 S | Chemi-Con | 1.14 | 0.3725 | 1.13
C201X5R2A475K125 AC | TDK Corporation | 0.75 | 0.2529 | 1.5
C06003C103K2RECT U | KEMET | 0.15 | 0.03633 | 0.3
RC0603FR-07100KL | YAGEO | 0.1 | 0.0052 | 0.1
RC0603JR-070RL | YAGEO | 0.1 | 0.00384 | 0.1
RLB0712-121KL | Bourns Inc. | 0.28 | 0.158 | 0.28
C0603C222J2GACTU | KEMET | 0.11 | 0.02416 | 0.11
CRCW060333K2FKEA C | Vishay Dale | 0.1 | 0.008 | 0.1
CL32A226KAJNNNE | Samsung Electro-Mechanics | 0.47 | 0.143 | 0.47
C0603C103K5RACTU | KEMET | 0.08 | 0.009 | 0.08
RC0603FR-07196KL | YAGEO | 0.1 | 0.0052 | 0.1
CR0603-FX06192ELF | Bourns Inc. | 0.1 | 0.0048 | 0.1
CMF5550R000FKEK7 0 | Vishay Dale | 0.56 | 0.173 | 0.56
LM5168FDDAR | Texas Instruments | 2.09 | 1.1058 | 2.09
Total | - | - | 2.5663 | 8.56
Table 3: Part Costs for Low Voltage Stage
Part Number | Manufactur er | Description | Quantity | Retail Cost (USD) $ | Bulk Purchase Cost (1k Units) ($) | Actual Cost ($)
296-6501-2-ND | Texas Instruments | IC OSC SGL TIMER 100KHZ 8-SOIC | 1 | 0.28 | 0.12315 | 0.28
TC4426ACPA | Microchip Technology | IC GATE DRVR LOW-SIDE 8DIP | 1 | 1.54 | 1.17 | 1.54
CPF0805B49 K9E | TE Connectivity | 49 kΩ, 0.1% resistor, 0603 | 1 | 0.11 | 0.11 | 0.11

| Passive Product
RT0402BRD0 715KL | YAGEO | 15 kOhms 0.1% resistor, 0.063W | 1 | 0.17 | 0.04567 | 0.17
RG2012P-10 2-B-T5 | Susumu | 1 kΩ, 0.1% resistor, 0603 | 1 | 0.1 | 0.04774 | 0.1
ERA-2AEB10 3X | Panasonic Electronic Components | 10 kΩ, 0.1% resistor, 0603 | 3 | 0.1 | 0.05637 | 0.3
CC0402KRX7 R9BB103 | YAGEO | 0.1µF, 50 V, 0402 | 2 | 0.08 | 0.0032 | 0.16
1N5817 | SMC Diode Solutions | DIODE SCHOTTKY 20V 1A | 2 | 0.18 | 0.04412 | 0.36
DMPH16M1 UPSW-13 | Diodes Incorporated | 12V N-MOS 12-V, Surface Mount | 1 | 0.32 | 0.32 | 0.32
0603N100J5 00CT | Walsin Technology Corporation | 10 pF, 50V Ceramic Capacitor, 0603 | 1 | 0.1 | 0.00824 | 0.1
GRM155R71 H392JA01D | Murata Electronics | 3.9 nF, 50V Ceramic Capacitor, 0603 | 1 | 0.1 | 0.01043 | 0.1
CL21B102KB ANNNC | Samsung Electro-Mechanics | 1 nF, 50V, Ceramic Capacitor, 0805 | 1 | 0.1 | 0.01176 | 0.1
RMCF0603F T3K00 | Stackpole Electronics | 3 kΩ, 1% resistor, 0603 | 1 | 0.1 | 0.0048 | 0.1
RMCF0603F T5K60 | Stackpole Electronics | 5.6 kΩ, 1% resistor, 0603 | 1 | 0.1 | 0.0048 | 0.1
RMCF0603F T47K0 | Stackpole Electronics | 47 kΩ, 1% resistor, 0603 | 1 | 0.1 | 0.0048 | 0.1
LM393ADR | Texas Instruments | Comparator (General Purpose) Open-Collector | 1 | 0.37 | 0.16465 | 0.37
ATTINY85-20 SU | Microchip Technology | IC MCU 8BIT 8KB FLASH 8SOIC | 2 | 1.50 | 1.25 | 3.00
Total | | | | 5.35 | 3.38 | 7.31

### 4.2 Labor

Table 4: Labor Costs
Team Member | $/hr | Total Hours | Cost (USD) $
Stephen | $40*2.5 | 10 hrs per week for 14 weeks | $14,000
Aidan | $40*2.5 | 10 hrs per week for 14 weeks | $14,000
Alex | $40*2.5 | 10 hrs per week for 14 weeks | $14,000
Total | | | $42,000

## 5. Conclusion

### 5.1 Accomplishments

Our design met all requirements the medical team of Neuroguard had us design. Our design worked both in simulation, and under ECE 445 lab constraints, worked as well. Our team persisted in the phase of PCB delays, difficulty with high voltage testing, and technical difficulties in the construct

### 5.2 Uncertainties

2kV testing was unable to be done in ECE 445 lab. Because of this, we are unsure if our high voltage design proposal is suitable for implementation with the Bovie ESU. There are concerts that as the device is triggered by output impedance, connecting a power supply to the output, which is needed to power the Neuroguard, may hinder operation, or inadvertently draw too much current and cause

### 5.3 Ethical considerations

With any device implemented in a medical setting, strict ethical considerations must be in place to ensure that no harm is done to the patient. This includes rigorous testing of the device, to ensure that to the fullest extent of our knowledge that it can work as prescribed, without causing harm to the patient. As a higher bar than doing no harm, we must demonstrate substantial beneficence to the patient, to ensure the device is not used needlessly.

### 5.4 Future work

While our work this semester in ECE445 has been fruitful in creating useful hardware for the neuroguard team, there is still much work to be done. The first course of action we recommend is a full characterization of the output of the Bovie Electrosurgical Generator. This will allow us to then design the proper hardware interface for the waveforms that are created. Without knowing the output forms of the ESG, we cannot successfully design any interface for the device. The next step would be to research and model the nerve stimulation and activation. This will involve creating finite element models of the tissue around the nerve during surgery, and the behavior of the ICBN itself, in order to tune the somatosensory evoked potentials. Then signal processing algorithms must be designed to convert electrode information of the evoked nerve into numerical approximations for distance the cautery pen is to the nerve. All of this must be followed by rigorous testing to ensure the device behaves properly and reliably before applications can be submitted to the appropriate government agency for regulatory approval, and eventual commercial release. This is a long and difficult road, littered with technical challenges and pitfalls, but we are confident that with the start we have made in ECE 445, the neuroguard team will be sure to succeed.

References

[1] M. Singhal, K. Kiunga, N. Kelhofer, P. Dullur, N. Chigullapally, S. Pappu, and M. L. Oelze, “Expanding the Scope of Intraoperative Neuromonitoring with Nerve-Specific Stimulatory Waveform Design,” Carle Illinois College of Medicine and Department of Electrical and Computer Engineering, University of Illinois Urbana-Champaign, Urbana, IL, USA.
[2 ]Bovie Medical Corporation, Specialist | PRO Electrosurgical Generator: User’s Guide, Ref. A1250S,
MC-55-237-001 Rev. 0, Clearwater, FL, USA, 2015.
[3] Texas Instruments, “LM5168 100-mA Synchronous Buck Converter,” datasheet, Rev. B, Apr. 2021. [Online]. Available: https://www.ti.com/lit/ds/symlink/lm5168.pdf
[4] IPC, “IPC-2221: Generic Standard on Printed Board Design,” IPC, Bannockburn, IL, USA, Std. IPC-2221, 1998
[5] Aaro N® SU RGI-C enter pro electr osurgical generator user’s guide. Available: http://images.tigermedical.com/Manuals/BOVA2350-20160412101734077.pdf
[6] LM393B, LM2903B, LM193, LM293, LM393 and LM2903 dual comparators 1 features . Available: https://www.ti.com/lit/ds/symlink/lm393.pdf

Appendix A Requirement and Verification Table

System Requirements and Verifications
Requirement | Verification | Verification status (Y or N)
Buck converter outputs 5V at 100mA, output voltage ripple is less than 0.25V | Oscilloscope measurement of output voltage with resistive load of 50Ω. Input power will be from Variac. Input will start at 30V AC and increment to 100V AC once safe device behavior is confirmed. | Y
Full bridge rectifier archives output DC voltage of 100V with voltage ripple less than 2V | Oscilloscope measurement of Vin trace | Y
Buck converter can handle 100mA to 300mA output transient in <10 uS. | Oscilloscope measurement of Vout with electronic load. | Did not have suitable E-Load to rigorously test this
3. The signal at pulse is measured to be 5V, outputting at the frequency desired between 50Hz-1kHz, and a pulse width between 100us - 1ms. | ● Probe test divider_out using a multimeter ● Confirm multimeter matches simulation waveform/breadboard results and is measured between the requirements listed. | Y
4. Confirm output is only high when microcontroller_out is high | ● Probe inputs and outputs of comparator with multimeter. ● Confirm Vref is input voltage is correct | Y
5. The V(divider_out) positive peak is greater than 0.5V, which is more than the 0.3V threshold needed by the comparator. | ● Probe test divider_out using a multimeter ● Confirm multimeter matches simulation waveform/breadboard results and is measured between the requirements listed. | Y
6. The Vref of the comparator is measured to be 0.3V with 5% tolerance. The output of the comparator is measured to be 3.3V when the input envelope detector is above 0.3V and 0V when below. | ● Probe inputs and outputs of comparator with multimeter. ● Confirm Vref is input voltage is correct | Y
7. When input voltage to microcontroller_in is LOW, then microcontroller_out is 5V. | ● Probe input and output of microcontroller with multimeter. | Y

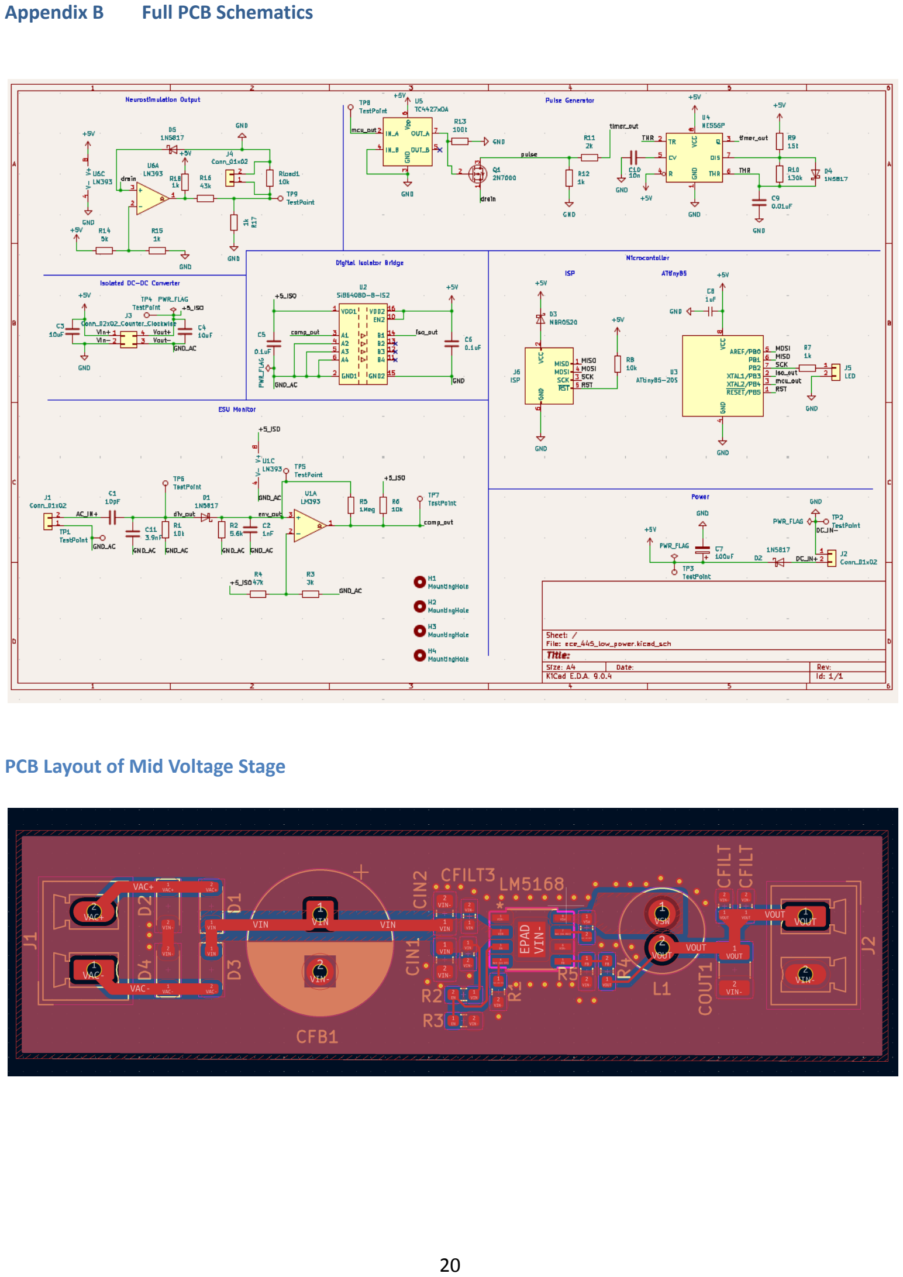
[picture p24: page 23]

Appendix B Full PCB Schematics

PCB Layout of Mid Voltage Stage


Full Schematic of Mid Voltage Stage

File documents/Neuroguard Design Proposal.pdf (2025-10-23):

## ECE 445

SENIOR DESIGN LABORATORY

## Design Document

# NeuroGuard

## A Dual Electrocautery-Nerve Monitoring Device to Prevent Injury during Mastectomy

### Team No. 31 AIDAN MORAN (afmoran2@illinois.edu) ALEX KREJCA (akrejca2@illinois.edu) STEPHEN SIMBERG (simberg3@illinois.edu)

### TA: Kai Chieh (Jeff) Chang Professor: Cunjiang Yu

### October 13, 2025

## Contents

2.3 Subsystem Requirements |

### 3 Cost and Schedule |

## 1 Introduction

We provide details as to the problem we aim to address revolving around nerve injuries during masectomies, along with our proposed solution, in context.

### 1.1 Problem

Over 100,000 mastectomies are performed yearly in the U.S., with 40-60% resulting in nerve injury that can lead to a variety of symptoms, notably post-surgical pain [1]. In particular, damage to the intercostobrachial nerve (ICBN) is common during mastectomy and axillary lymph node dissection, a set of procedures common in treating metastatic breast cancer. Recently, surgeons have begun utilizing nerve-sparing techniques to ensure greater patient quality of life; however, these innovative techniques require meticulous dissection that can be complicated by anatomical variation and intraoperative bleeding.This highlights an urgent need for a device that provides real-time feedback to surgeons, enhancing safety and precision while also being easily integrated into existing workflows. To address this problem, we propose NeuroGuard, a device designed to alert surgeons when they are approaching the ICBN nerve during operations, thereby reducing nerve injury rates and improving patient outcomes.

### 1.2 Solution

Inspired by recent multifunctional surgical devices like a dual monopolar probe and suction tool, we are working with the NeuroGuard team to integrate contactless nerve detection and cautery functionalities into a single, cost-effective device. Over the course of the semester, we will work to design and simulate a circuit that demonstrates the ability to switch between predefined electrocautery and nerve stimulation waveforms at specified time intervals. We will work to prototype this circuit that can be integrated with an electrosurgical unit and standard monopolar electrocautery probe. This project is a proof of concept for the hardware platform, demonstrating the capability to integrate power conversion and waveform generation that could be used with a standard cautery probe. The scope is strictly limited to the development and testing of this hardware; the detection of neural activation and the development of a feedback mechanism are considered future work beyond the scope of this project.

### 1.3 Visual Aid


Figure 1: Overview of the Neuroguard system


Figure 2: Initial design concept from the Neuroguard team

### 1.4 High-Level Requirements

To consider our project successful, we aim to accomplish the following goals:

1. Creation of 2000V to 5V step down converter system that is compatible with existing cautery power supplies
a. Suitable sub systems for safe testing. This will involve a high voltage inverter and transformer to step down the voltage from 2000V to ~100V. This 100V AC will then go through a rectifier and buck converter to step it down to a suitable 5V that will be used by the circuit components.
2. Creation of suitable nervous stimulatory waveform from a 555 timer IC
3. Creation of a power MOSFET and a super capacitor to provide suitable pulsed current waveforms for neuron detection
4. Creation of interface hardware that will detect when to send out the nerve stimulating waveform.

### 1.5 Circuit Design

The system functions by employing pulse width modulation, alternating the standard cautery voltage settings with a smaller, pre-calculated neurostimulator waveform. These settings would reduce electrical noise interference, while enabling accurate downstream sensing of neural activation. The NeuroGuard system itself would reside between the electrosurgical unit (ESU) and the probe, modulating the waveform to include a component that allows for contactless activation of the ICBN. This modulation could occur by harvesting the existing power source of the ESU at specific time points within the duty cycle, or as an external power source that overlays the nerve-specific waveform onto the existing cautery duty cycle. In the first setup, the high-frequency AC current from the ESU would be rectified to a DC current, followed by a voltage step down mechanism and filtering. A supercapacitor can serve as the charge storage mechanism, with the discharge timed by a MOSFET, 555 timer, or other pre-programmed timing component. In the second setup, an external power unit, rather than the ESU, can be the source of the nerve-specific stimulation waveform.

## 2. Design Overview

### 2.1 Block Diagram


Figure 3: Block Diagram

The block diagram can be roughly divided into two main parts. The power section must safely

and reliably step down 2000V to a 5V 100mA output. The signal section of this project must

detect when the Cautery tool is in the off state, and then create a suitable nerve stimulatory

waveform that will be outputted to the cautery tool through a power mosfet and driver circuitry.

### 2.2 System Overview

### 2.2.1 High Voltage Stage

A single stage buck is infeasible to safely and efficiently step down a 2000V DC input to a 5V DC output. We use 2000V DC as this is the output of the electrosurgical unit (ESU). Because of this, we will be implementing a multi stage power conversion system. The high voltage stage will take the 2kV DC and invert it to create a 2kV DC output. This will go through a transformer that will then step it down to 100V AC. This 100V AC will then be sent to a full bridge rectifier and filtering circuitry.

The preliminary design is centered around a Royer Oscillator, which is a type of relaxation oscillator. The royer oscillator is a self oscillating, push pull, AC/DC converter which uses a resonant LC circuit and the saturation of the transformer core to create an oscillatory AC output. It is widely used for low cost, low power DC to AC converters. There are a large number of advantages to using this type of circuit. As all the line and load regulation is done at the mid voltage stage, we do not need precise inverter circuitry on the high voltage inverter. Additionally, the entirely analog circuitry requires only the input power to run. Oftentimes inverters will need a low voltage rail to power the driver IC, which would not be feasible on our circuit. The most difficult part of this circuit is finding BJT’s and a transformer that are properly rated for the oscillatory frequency and voltage. The design is based on the Masters Thesis of Scott McClusky from the California Polytechnic University, San Luis Obispo [5]. This output will then go to a 20:1 transformer to provide the mid voltage stage with the 100V AC it will use.


Fig 2.2.1.1: Circuit diagram of Royer Oscillator circuit

Significant considerations must be made when designing a PCB to handle multiple kilovolts. IPC 2221-b specifies design clearances, creepage, and dialectic breakdown for high voltage PCB designs. Additionally, the IEC 60601 specifies device tolerances and safety standards for any medical grade device. Another advantage of this design is the transformer provides isolation between the input and output, ensuring any malfunction on the high voltage side has no way to short through to the output of the neuroguard.


Fig 2.2.1.2: Another possible self resonant oscillator circuit. This topology utilizes a separate gate driver circuit. This is advantageous as it reduces the gate voltage compared to a normal Royer or Mizzolli self resonant circuit.

Requirement | Measurement
Output a stable 2000V AC output at 1kHz - | Output measurement on oscilloscope with

100kHz frequency | appropriate voltage shielding.
Meets all IPC2221-b and IEC60601 requirements for high voltage PCB design | Design rule check and verification in KiCAD or other design software.
No excessive distortion of input voltage source | Will require a specialized EMI measurement device.

### 2.2.2 Mid Voltage Stage

The Mid Voltage Stage contains the rectifier and filtering circuitry, as well as a final buck converter to do the final step down to 5V DC. This 100V AC input, once rectified and filtered, will output 100V DC that is then sent to a buck converter that will do the final step down to 5V DC. The Buck converter chosen for this task is the Texas Instruments LM5186. It is rated to a 120V input and capable of supplying a maximum of 300mA on the output. The synchronous buck converter features a variety of safety features, including over current protection, power good flag, soft start (to avoid start up transients), under voltage lockout protection, and redundant internal bandgap monitoring. Input to this is a full bridge rectifier composed of 4 BAV21W-7-F fast recovery diodes rated for 400mA and 200V each. A single 100 μF electrolytic capacitor is placed across this full bridge rectifier to smooth the output. A full schematic and detailed description of each subsection of this design is given below.


Fig 2.2.2.1: Schematic of Mid Voltage Step Down

Fig 2.2.2.2: PCB Layout of Mid Voltage Step Down


Fig 2.2.2.3: 3D Rendering of Mid Voltage Step Down

Buck Converter Layout and Design - Output Filtering

The output filtering is a crucial design element of the buck converter, and critical to its function. The inductor and output capacitors for this stage are sized appropriately to provide the necessary output current and minimal voltage ripple. These calculations were completed using formulas given from the Application and Implementation of the section of the LM5186 Data sheet [3]


Fig 2.2.2.4: Output filtering of Mid Vin Stage

The Inductor and Capacitor (L1 and COUT1) were sized using the formula listed below. CFILT1 and CFILT2 are high frequency noise capacitors. While not contributing significantly to the power conversion of the buck converter, they give any high frequency noise ( >1Mhz) a low impedance path to ground, increasing the stability of the buck converter and mitigating any noise going to the output.

Fig 2.2.2.5: Output Inductor Formula

Fig 2.2.2.6: Output Capacitor Formula

These values were then calculated using Fsw = 750kHz, Vin =100V, Vout=5V, Ipri = 0.1A,
Ipk = 0.3 A, and ∆Vo = 0.5V. The switching frequency was chosen as 750kHz. This is lower than the devices maximum switching frequency, of 1000kHz, however due to the minimum on time of 50nS and our very low duty cycle, a lower frequency was chosen in order to avoid minimum time on constraints. This then gave an Rt value (timing resistor) value of 33.2 kΩ.


Fig 2.2.2.7: PCB Layout of Switch node and output Filtering.

Buck converters are inherently highly sensitive to PCB layout design. The high di/dt transients present at the output switch node (VSW) of a buck converter mean that any parasitic inductances in the PCB layout will create undesirable voltage spikes along the output. The switch node (VSW) is minimized as much as possible, and surrounded by ground Vias to aid with thermal dissipation and EMI protection. Clearances of 25 mil are maintained around the switch node to prevent arcing, in accordance with IPC-2221b clearance requirements [4], specifying a minimum of 0.5mm (19.3 mil), for a 100V external trace.

Buck Converter Layout and Design - Input Filtering and Enable Resistors

The Input filtering is critical to the buck converters function and integration into the wider power system. Buck converters will inherently draw a square wave type current, which can create voltage spikes from the parasitic inductances on the input line. Filtering capacitors are needed to smooth out this current to ensure integration with the wider electrical system, and provide charge for the current pulses that a buck converter will take in. A 100μF electrolytic capacitor is used to smooth out the pulsed DC from the full wave rectifier. This gives us a total input ripple to the buck converter of less than 2V. The inverter switching frequency will be selected to be significantly less than the buck switching frequency, such that the feedback loop on the buck can handle the voltage ripple on the input. The Enable resistor divider ensures that the buck will switch on only when it receives a suitable input voltage, in this case ~16V. This prevents the buck converter from trying to switch with an abnormal input, which could potentially cause damage to the device.


Fig 2.2.2.8: Buck converter Input Filtering and Enable Resistors


Fig 2.2.2.9: PCB Layout of input filtering capacitors (CIN1, CIN2, CFILT3, CFILT4).

The smaller input capacitors are sized at 4.7 μF for CIN1 and CIN2, and 10nF for CFILT3 and CFILT4. These capacitors are placed as close as possible to the input of the device to mitigate parasitic inductances, which would cause voltage spikes. The filtering capacitors are 10nF each, and similar to the output filtering capacitors, are in place to provide a low impedance path for high frequency noise. These capacitors are all ceramic SMD packages, and are rated at 200V. This higher rating is necessary to avoid derating in the capacitors, which causes ceramic capacitors to become less effective at high voltages.

Buck converter Layout and Design - Feedback Loop

The feedback loop of a buck converter is incredibly important to help the converter maintain a stable output voltage and handle load transients appropriately. A simple voltage divider feedback loop is used here. If this design prevents insufficient stability during testing, then a feed forward capacitor (C ~50pF - 100pF), may be placed in parallel with RFBT to help with stability. The values of the feedback resistors were calculated from the formula below.

Fig 2.2.2.10: Feedback Formula

Here, VOUT = 5V, and VREF = 1.2V. There are an infinite number of possible combinations to use, but the design must take into account that higher resistances will increase efficiency, but make the feedback loop more susceptible to noise, and vice versa for a lower feedback resistance. To balance these considerations, a value of 196 kΩ was selected for RFBT, and a value of 61.9kΩ was selected for RFBB. The PCB layout is given below. It is important to ensure that the output of the feedback resistor is placed as close to the FB pin of the IC as possible to avoid noise coupling. Additionally the Vout line to the feedback is kept as short as possible and ground vias are placed in between the feedback resistors and the switch node, again to prevent noise coupling.


Fig 2.2.2.11: Feedback Resistor Layout.

Buck converter Layout and Design - Thermal and EMI considerations.

Despite being a relatively low power design (0.5W), and operating at moderate efficiency (~60%), this buck will still require the dissipation of a non-negligible amount of power. The PCB is designed to allow high thermal conduction from the IC to the board, and then from the board to the ambient environment. The board is designed with unobstructed ground planes above and below to allow for efficient heat dissipation. Additionally, the ground vias on top and below the board allow heat to effectively conduct to the bottom ground plane, where it then can be more easily dissipated. An IC package with a large copper pad on the bottom of the device is connected to the ground plane to allow for better heat dissipation as well.

As buck converters are inherently noisy components, EMI (Electromagnetic Interference) must be accounted for in the schematic and PCB layout. A large amount of ground vias are placed around the device and the switch node to prevent conducted noise along the ground plane. If there is excessive distortion of the input supply, an EMI filter may be added in between the full bridge rectifier and filtering capacitors to suppress this.


Fig 2.2.2.12: Thermal and EMI considerations around the conductor.

Buck converter Layout and Design - Simulation, Testing, and Verification.

This design was simulated in PSpice for TI (whose simulation software comes from Cadence), and performed well. A result of the simulation is shown below. The Red trace is enable voltage, the green trace is output voltage, the dark blue trace is input voltage, the yellow trace is feedback voltage, and the cyan trace is inductor current. This shows stable operation with a nominal output voltage of 5V and minimal voltage ripple.


Fig 2.2.2.13: Cadence simulation of Buck converter and rectifier.

Listed below are the performance criteria for this design, and the method of verification.

Requirement | Verification
Buck converter outputs 5V at 100mA, output voltage ripple is less than 0.25V | Oscilloscope measurement of output voltage with resistive load of 50Ω. Input power will be from Variac. Input will start at 30V AC and increment to 100V AC once safe device behavior is confirmed.
Full bridge rectifier archives output DC voltage of 100V @5% with voltage ripple less than 2V | Oscilloscope measurement of Vin trace

Buck converter can handle 100mA to 300mA output transient in <10 uS.

Oscilloscope measurement of Vout with electronic load.

### 2.2.3 Timer & Low Voltage Stage


Fig 2.2.3: Low Voltage Stage Circuit.

The input being the 5V DC from the mid-voltage stage, a 555 timer IC is used to generate a 0.1V 50-1kHz signal, with a pulse width 100us - 1ms. This is selectively discharged through a resistor (simulating nerve tissue) via an N-channel MOSFET, whose gate is driven by a 5V pulse signal from the microcontroller via a gate driver. When the gate receives a high signal, the MOSFET turns on, allowing the capacitor to release its energy as a precise stimulation pulse across the load.

R7 and R8 to create a 0.1V, 1kHz, 100 µs pulse signal can be chosen to be R7 = 15kOhms, R8 = 130kOhms.common NE555) uses different formulas depending on its operating mode: for astable mode, the formulas are: tHIGH=0.693(RA+RB)C, tLOW=0.693(RB)C, T = tHIGH + TLOW.

Requirements | Verifications
1. The signal at pulse_0.1V is measured to be 0.1V, outputting at the frequency desired between 50Hz-1kHz, and a pulse width between 100us -1ms. | ● Probe pulse 0.1V using a multimeter ● Confirm multimeter matches simulation waveform/breadboard results and is measured between the requirements listed.
2. Confirm output is only high when mircocontoller_out is high | ● Probe Rload and microcontroller_out. ● Confirm 0V is measured when microcontoller out is low, and a pulse signal is measured when it is high.

### 2.2.4 ESU Monitor & Microcontroller Stage


Fig 2.2.4: ESU Monitor Circuit.

The microcontroller detects when to alternate between the standard cautery function

(pass-through) and the nerve stimulation waveform. The ESU source is the input, which is a 2000V AC source with a 357-500 kHz, and a Duty Cycle from 5-75%. It also takes as input the 5V DC from the low voltage stage and uses it to create a Vref of 0.3V in the LM393 comparator. This PCB provides the Cautery Tool Monitoring, which detects the ON and OFF duty cycles of the ESU source via a capacitive voltage divider that feeds into an envelope detector, and to the comparator in order to detect the OFF periods of duty cycle of the ESU, which is when the nerve stimulation is allowed to be delivered. Comp_out is the input to the microcontroller, which outputs a HIGH signal when the comp_out is LOW and vice-versa. This will output a signal to the mosfet driver from section 2.3.3 that when high (5V), will turn MOSFET turns on, allowing the stimulation pulse across the load during the OFF cycles.

C1 and C2: The division ratio is approximately C1 / (C1 + C2). Ratio ≈ 10pF / (10pF + 3900pF) = 10 / 3910 ≈ 1/391 This reduces the peak voltage from 1850 to 2000V down to a much more usable 4.7V - 5V AC.

R2 and C3: These components create the crucial RC time constant (τ). τ = R * C = 5,600 Ω * 0.000000001 F = 5.6 µs. It must be longer than the carrier period, and the carrier period at its lowest is 1 / 307kHz ≈ 3.26 µs from ESU manual [6]. The 5.6 µs is long enough that C3 does not discharge between peaks.

Requirements | Verifications
1. The peak V(divider_out) is measured to be below 10V and the positive peak greater than 0.5V, which is more than the 0.3V threshold needed by the comparator. | ● Probe test divider_out using a multimeter ● Confirm multimeter matches simulation waveform/breadboard results and is measured between the requirements listed.

2. The diode properly acts as a half-wave rectifier and outputs a signal matching the output of V(divider_out) | ● Probe test points of envelope with multimeter ● Confirm the maximum voltage is between below 10V and the positive peak greater than 0.5V, which is more than the 0.3V threshold needed by the comparator.
3. The Vref of the comparator is measured to be 0.3V with 5% tolerance. The output of the comparator is measured to be 3.3V when the input envelope detector is above 0.3V and 0V when below. | ● Probe inputs and outputs of comparator with multimeter. ● Confirm Vref is input voltage is correct

### 2.3 Subsystem Requirements

### 2.3.1 High Voltage Stage

Power supply can successfully output 100V AC 5% tolerance. The entire apparatus is safe to use under medical criteria.

### 2.3.2 Mid Voltage Stage

Power supply can successfully output 5V DC 5% tolerance at 100mA 5% tolerance with voltage ripple less than 10% ( Output supply maximum ripple is from 4.5V to 5.5V, DC output is maintained from 4.75V to 5.25V). The entire apparatus is safe to use under medical criteria.

### 2.3.3 Low Voltage Stage

When the Mosfet receives a high signal, the MOSFET turns on, allowing the capacitor to release its energy as a precise stimulation pulse across the load is measured to be 0.1V at 50 Hz - 1 kHz. The waveform generated during the OFF period is still the ESU source.

### 2.3.4 ESU Monitor & Microcontroller Stage

The microcontroller, given a 5V input with a certain % Duty Cycle, is able to time when nerve stimulation occurs. The microcontroller must output 5V to the Mosfet Driver during the OFF portion of the Duty Cycle, and according to the 555 timer.

### 2.4 Tolerance Analysis

Significant considerations must be taken on the PCB layout and design for this power system. High voltage DC will require larger trace tolerances and specialized PCB dielectric to prevent arcing between traces. This entire apparatus must then be placed into an insulating chamber for improved safety. While buck converters are generally the most efficient method to step down DC voltages, because of the large jump from input voltage to output voltage required (100V DC to 5 V DC), efficiency will be closer to ~50% depending on the specific buck converter chosen. Thermal considerations are incredibly important so the buck converter does not overheat and shut down. The final large consideration is EMI filtering from the buck converter and Inverter sub systems. The DC power supply NeuroGuard will receive is incredibly sensitive to backpropagated conducted EMI. Significant filtering will need to be in place in order to ensure that this does not disrupt the cautery power supply.

### 3.1 Cost Analysis

Low Voltage and Microcontroller Part and Cost Analysis

Below is the table of parts used in the low voltage and microcontroller part of the circuit, and

their respective cost. The exact cost is of the basic components used, more parts were used for

testing and redundancy purposes. The majority of parts in these subsystems were acquired from

the ECE supply center for free, but the unit cost is still provided.

Part Number | Description | Quantity | Cost (USD) $
296-6501-2-ND | IC OSC SGL TIMER 100KHZ 8-SOIC | 1 | 0.28
TC4426ACPA | IC GATE DRVR LOW-SIDE 8DIP | 1 | 1.54

CPF0805B49K9E | 49 kΩ, 0.1% resistor, 0603 | 1 | 0.1
RT0402BRD0715KL | 15 kOhms 0.1% resistor, 0.063W | 1 | 0.1
RG2012P-102-B-T5 | 1 kΩ, 0.1% resistor, 0603 | 1 | 0.1
ERA-2AEB103X | 10 kΩ, 0.1% resistor, 0603 | 3 | 0.3
CC0402KRX7R9BB103 | 0.1µF, 50 V, 0402 | 2 | 0.16
1N5817 | DIODE SCHOTTKY 20V 1A | 2 | 0.18
DMPH16M1UPSW-13 | 12V N-MOS 12-V, Surface Mount | 1 | 0.32
0603N100J500CT | 10 pF, 50V Ceramic Capacitor, 0603 | 1 | 0.1
GRM155R71H392JA0 1D | 3.9 nF, 50V Ceramic Capacitor, 0603 | 1 | 0.1
CL21B102KBANNNC | 1 nF, 50V, Ceramic Capacitor, 0805 | 1 | 0.1
RMCF0603FT3K00 | 3 kΩ, 1% resistor, 0603 | 1 | 0.1
RMCF0603FT5K60 | 5.6 kΩ, 1% resistor, 0603 | 1 | 0.1
RMCF0603FT47K0 | 47 kΩ, 1% resistor, 0603 | 1 | 0.1
LM393ADR | Comparator (General Purpose) Open-Collector | 1 | 0.37
STM32F401RBT6 | IC MCU 32BIT 128KB FLASH | 1 | 4.96
PCB Order | PCB | 1 | 0.5
Labour | Cost of Labour ($15/hour) | 3 hour | 45
Total | — | | 54.512

Mid Voltage Part and Cost Analysis

Below is a table of parts, and their respective cost for the mid voltage source. As this is dealing

with specialized high voltage components, the cost is significantly higher than what would be

expected for the same low voltage component. As additional parts were ordered for redundancy and testing purposes, the exact cost of the project does not precisely reflect this spreadsheet.

Part Number | Description | Quantity | Cost (USD) $
BAV21W-7-F | 200 V, 400 mA small-signal diode, SMD, SOD-123 | 4 | 0.4
OSTTC022162 | 2-position screw terminal block, 5.08 mm pitch | 2 | 1.14
EKMQ161ELL101MK2 5S | 100 µF, 160 V radial electrolytic capacitor | 1 | 1.13
C2012X5R2A475K125 AC | 4.7 µF, 100 V, 0805 MLCC capacitor | 2 | 1.5
C0603C103K2RECTU | 0.01 µF (10 nF), 200 V, 0603 MLCC | 4 | 0.6
RC0603FR-07100KL | 100 kΩ, 1% resistor, 0603 | 1 | 0.1
RC0603FR-0710KL | 10 kΩ, 1% resistor, 0603 | 1 | 0.1
RC0603JR-070RL | 0 Ω jumper resistor, 0603 | 1 | 0.00292
RLB0712-121KL | 120 µH radial inductor | 1 | 0.28
C0603C222J2GACTU | 2,200 pF, 200 V, 0603 MLCC | 1 | 0.01974
CRCW060333K2FKEA C | 33.3 kΩ, 1% resistor, 0603 | 1 | 0.1
CL32A226KAJNNNE | 22 µF, 25 V, 1210 MLCC | 1 | 0.14376
C0603C103K5RACTU | 10 nF, 50 V, 0603 MLCC | 2 | 0.16
RC0603FR-07196KL | 196 kΩ, 1% resistor, 0603 | 1 | 0.1
CR0603-FX-6192ELF | 61.9 kΩ, 1% resistor, 0603 | 1 | 0.1
LM5168 | 120V 0.1A Synchronous buck convert | 1 | 3.77
CMF5550R000FKEK70 | 50 Ω ±1% metal film resistor (through-hole) | 1 | 0.56
PCB Order | PCB | 1 | 0.5
Labour | Cost of Labour ($15/hour) | 3 hour | 45
Total | — | | 55.70642

Cost Analysis for High Voltage Section.

The design of the high voltage section has not been finalized, and thus an exact value cannot be

given. Based on the circuit design, a rough estimate can be provided. The high voltage BJT will

be about $4 for two. High voltage capacitors and resistors will total to approximately $10. A

specialized high voltage transformer will cost anywhere from $10 - $20. While a specialized

high voltage PCB and enclosure may cost anywhere between $20 and $40. This will bring the

total cost for this section of the design to $50 for a conservative estimate and $100 in a worse

case scenario.

Labor Cost

Team Member | $/hr | Total Hours | Cost (USD) $
Stephen | $40 | 10hrs per week for 14 weeks | $5,600
Aidan | $40 | 10hrs per week for 14 weeks | $5,600
Alex | $40 | 10hrs per week for 14 weeks | $5,600

### 3.2 Schedule

Week of | Task | Group Member(s)
10/13 | Finalize Low Voltage/Microcontroller Design Draft PCB in KiCAD Second Round PCBway Order (Low Voltage) | Alex, Stephen Alex All
10/20 | Microcontroller Selection Assemble First PCB | Alex Aidan

| Program Cauterizing Detection Prepare for Breadboard Demo | Stephan All
10/27 | Finalize GPIO Pin Configurations Finalize High Voltage Design Breadboard Demo 2 | Stephan Aidan All
11/3 | Assemble Second PCB Test First PCB Order High Voltage PCB | Stephan Alex Aidan
11/10 | Test Second PCB Integrate Different Voltage Systems Assemble & Test High Voltage PCB Order Final PCB (If Necessary) | Alex All Stephen Aidan
11/17 | Mock Demo Team Contract Assessment Test System Integration Start on Final Report and Presentation | All All All All
11/24 | Fall Break Finalize Presentation and Report | All
12/1 | Final Demo Mock Presentation Work on Final Report | All All All
12/8 | Final Presentation Final Paper Due Lab Notebook Due | All All All

## 4 Ethics & Safety

To make sure our group is working on our project safely and effectively, we will follow the IEEE

Code of Ethics that was adopted by the IEEE Board of Directors in 2020[2]. We understand that technologies affect the quality of life around the world and we must work with a high ethical

standard as a professional team. Some of the most important, but not the only, ethics to follow

for our team are:

### 1. Seek, accept, and offer honest criticism of technical work, acknowledge and correct

errors, be honest, and realistic in stating claims or estimates based on available data

[2].

It is important to work as a team to keep an open mind that we will not accomplish every

part of our project perfectly right away. During our TA meetings, we will be able to

receive feedback, positives or criticisms, to improve on our project. In our lab notebook,

we will take note of all our progress and data, along with what we discussed in TA

meetings, to provide a basis for our project claims.

### 2. Treat all persons fairly and with respect, to avoid harassment or discrimination, and

to avoid injuring others [2].

As we work throughout the project, we will spend time together and apart to create the

final product. When we work together, we must listen to each other and consider every

one’s opinions in a discussion about our project. Everyone’s opinion needs to be

considered for there to be a fair decision-making process.

### 3. Work to improve our technical competence but consider our qualification from

training or experience and disclose notable limitations [2].

Since completing our proposal document and review, all members of the team have

completed the soldering and KiCAD assignment which builds a basic understanding for

designing our PCBs. Also, we have met with the Neuroguard Carle Medical team to

understand their design aspirations and how to adapt our design with the cauterizing machine. As we continue the project, we will continue to expand our knowledge as more

questions arise during our implementation.

### 4.1 Risk Analysis

To ensure safety in our design and following all regulations, we will take a number of

precautions to minimize danger in development and operation of our device. Because we will be

dealing with high voltage, possibly of 2000 Volts if connected to the hospital supply, it is

important to make sure all components included in our design can withstand these voltage levels,

even after step-down converters are included. Again, because this is a project dealing with high

voltage, we will create a Safety Manual and demonstrate that our project complies with the

safety manual at the time of demo.

Another risk to consider is the large losses that can be found in our electrical system.

Because we are dealing with high voltage, these losses can generate lots of heat which can be

dangerous for the device and the user. Therefore, we will make sure all components in the device

operate at a temperature under its rating and use ventilation tools, as required. Also, we will

make sure that all devices, such as microcontrollers, and software follow relevant licensing

requirements.

## 5 References

1) M. Singhal, K. Kiunga, N. Kelhofer, P. Dullur, N. Chigullapally, S. Pappu, and M. L.

Oelze, “Expanding the Scope of Intraoperative Neuromonitoring with Nerve-Specific

Stimulatory Waveform Design,” Carle Illinois College of Medicine and Department of

Electrical and Computer Engineering, University of Illinois Urbana-Champaign, Urbana,

IL, USA.

2) IEEE. “”IEEE Code of Ethics”.” (2016), [Online]. Available: https://www.ieee.org/

about/corporate/governance/p7-8.html (visited on 09/19/2025).

3) Texas Instruments, LM516x, 0.65A/0.3A, 120V Absolute Maximum, Step-Down Converter

With Fly-Buck™ Converter Capability (datasheet, Rev. B), Dec. 2021, revised Dec. 2024.

[Online]. Available: https://www.ti.com/lit/ds/symlink/lm5168.pdf

4) IPC, IPC-2221B: Generic Standard on Printed Board Design, Nov. 2012. [Online].

Available: https://www.electronics.org/TOC/IPC-2221B.pdf

5) J. C. Araki, “Design of a High Voltage, High Frequency Royer Oscillator,” M.S. thesis,

Dept. of Electrical Engineering, California Polytechnic State University, San Luis

Obispo, CA, 2009. Available:

https://digitalcommons.calpoly.edu/cgi/viewcontent.cgi?article=1266&context=theses

6) Aaro N® SU RGI-C enter pro electr osurgical generator user’s guide. Available:

http://images.tigermedical.com/Manuals/BOVA2350-20160412101734077.pdf

7) LM393B, LM2903B, LM193, LM293, LM393 and LM2903 dual comparators 1 features •.

Available: https://www.ti.com/lit/ds/symlink/lm393.pdf

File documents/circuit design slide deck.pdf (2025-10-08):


Cutting Edge Precision without Cutting Nerves

# NeuroGuard

Meet Leila; 36 y/o F hx of breast cancer suffering from post surgical pain; ICBN; Intercostobrachial Nerve (ICBN)

Nerve Injury rate with mastectomy; Over 100,000/year in US[2]

Design Constraints; Real-Time Feedback; Contactless Nerve Detection; Surgical Functionality; Patient Injury; Cost; Integration

NeuroGuard; Detects anatomically-important nerves; Provides real-time feedback; Integrates with existing tools; Nerve-specific (based on modeling)

## beyond 1 cm distance during electrocautery

# SSEPs


The Bi Lab, Brigham and Women’s Hospital

Somatosensory evoked potentials:
- Intraoperative measurement of peripheral nerve activation through stimulation

Head SSEPs setup

# Neuroguard Components


3. Sensory nerve detection via distal electrode
1. Stimulation during 100ms duty cycle
2. Recording response
4. SSEPs → real-time feedback

# Integration with existing tools

## - We envision our device as an add on to electrocautery generator


### - Lower costs, more accessible, small learning curve - NeuroGuard probes which are compatible with Bovie and smoke evac systems


# Duty cycle modification ideas

# Electrocautery concepts


From bovie manual

Design concept #2: external power

ESU (AC current source); 555 timer, microcontroller (PWM); MOSFET; MOSFET Driving circuit; Tissue; Neurostimulation Signal/ Capacitor or something

the Bovie patent (US 9,326,810 B2)

# Goals/constraints

We would like to modulate the duty cycle generated by standard electrocautery units, to incorporate a stimulatory component that is specifically targeted for nerve activation


- Monopolar setup
1. Electrocautery duty cycle: 5-50%
2. Electrocautery frequency: 500 kHz - 3 MHz
3. Nerve stimulation frequency: 50 Hz - 1 kHz
a. Pulse width: 100us - 1ms

# Design ideas

### 1. Time division multiplexing

a. Nerve stimulation voltage delivered during OFF periods of duty cycle
b. Superimpose the neurostimulator frequency during the OFF phase of the electrocautery duty cycle
c. External device (Arduino microcontroller) could take in signal from electrocautery and time when nerve stimulation occurs (or have it be pre-programmed based on %)
d. Measure with oscilloscope

### 2. Low frequency modulation

a. I.e. blended current
b. Modulate electrocautery with nerve stimulation frequency
c. Noise issues → filtering

### 3. Harmonic Filtering

a. Separate tip


ESU (AC current source); RF rectifier (Schottky diode) + capacitor; monostable 555 timer, microcontroller; Voltage step down; Energy storage; (supercapacitor); cautery probe; portion of ON period; Design concept #1; Low pass filtering; MOSFET

- Voltage step-down:
- Transformer, DC-DC converter, low-dropout regulator

Design concept #1; Powering nerve stim with ESU; ESU (AC current source); Voltage reference IC (2 V); Voltage divider (0.2 V); RF rectifier (Schottky diode) + capacitor; monostable 555 timer, microcontroller; Low pass filtering; Energy storage

- Rectifier + filter high frequency: AC → DC current
- Voltage step-down: DC-DC converter, low-dropout regulator
- Energy storage → powers OFF periods of duty cycle (supercapacitor)

ESU; NeuroGuard; probe; circuit; Storage and switching mechanisms; Filtering; Recording electrode; nerve

ESU (AC current source); 555 timer, microcontroller (PWM); MOSFET; MOSFET Driving circuit; Tissue; MOSFET Change current frequency/volts; Design concept #3; 555 timer controls when nerve stimulation is delivered

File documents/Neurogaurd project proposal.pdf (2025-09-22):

## ECE 445

SENIOR DESIGN LABORATORY
PROJECT PROPOSAL

# NeuroGuard

## A Dual Electrocautery-Nerve Monitoring Device to Prevent Injury during Mastectomy

### Team No. 31 AIDAN MORAN (afmoran2@illinois.edu) ALEX KREJCA (akrejca2@illinois.edu) STEPHEN SIMBERG (simberg3@illinois.edu)

### TA: Kai Chieh (Jeff) Chang Professor: Cunjiang Yu

### September 19, 2025

## Contents

### 1 Introduction . . . 2

### 2 Design Overview . . . 5

### 3 Ethics & Safety . . . 8

References . . . 10

### 1 Introduction

We provide details as to the problem we aim to address revolving around nerve injuries during masectomies, along with our proposed solution, in context.

### 1.1 Problem

Over 100,000 mastectomies are performed yearly in the U.S., with 40-60% resulting in nerve injury that can lead to a variety of symptoms, notably post-surgical pain [1]. In particular, damage to the intercostobrachial nerve (ICBN) is common during mastectomy and axillary lymph node dissection, a set of procedures common in treating metastatic breast cancer. Recently, surgeons have begun utilizing nerve-sparing techniques to ensure greater patient quality of life; however, these innovative techniques require meticulous dissection that can be complicated by anatomical variation and intraoperative bleeding.This highlights an urgent need for a device that provides real-time feedback to surgeons, enhancing safety and precision while also being easily integrated into existing workflows. To address this problem, we propose NeuroGuard, a device designed to alert surgeons when they are approaching the ICBN nerve during operations, thereby reducing nerve injury rates and improving patient outcomes.

### 1.2 Solution

Inspired by recent multifunctional surgical devices like a dual monopolar probe and suction tool, we are working with the NeuroGuard team to integrate contactless nerve detection and cautery functionalities into a single, cost-effective device. Over the course of the semester, we will work to design and simulate a circuit that demonstrates the ability to switch between predefined electrocautery and nerve stimulation waveforms at specified time intervals. We will work to prototype this circuit that can be integrated with an electrosurgical unit and standard monopolar electrocautery probe. This project is a proof of concept for the hardware platform, demonstrating the capability to integrate power conversion and waveform generation that could be used with a standard cautery probe. The scope is strictly limited to the development and testing of this hardware; the detection of neural activation and the development of a feedback mechanism are considered future work beyond the scope of this project.


### 1.3 Visual Aid

Figure 1: Overview of the Neuroguard system

Figure 2: Initial design concept from the Neuroguard team

### 1.4 High-Level Requirements

To consider our project successful, we aim to accomplish the following goals:

1. Creation of 2000V to 5V step down converter system that is compatible with existing cautery power supplies
a. Suitable sub systems for safe testing. This will involve a high voltage inverter and transformer to step down the voltage from 2000V to ~100V. This 100V AC will then go through a rectifier and buck converter to step it down to a suitable 5V that will be used by the circuit components.
2. Creation of suitable nervous stimulatory waveform from a 555 timer IC
3. Creation of a power MOSFET and a super capacitor to provide suitable pulsed current waveforms for neuron detection
4. Creation of interface hardware that will detect when to send out the nerve stimulating waveform.

Circuit Design

The system functions by employing pulse width modulation, alternating the standard cautery voltage settings with a smaller, pre-calculated neurostimulator waveform. These settings would reduce electrical noise interference, while enabling accurate downstream sensing of neural activation. The NeuroGuard system itself would reside between the electrosurgical unit (ESU) and the probe, modulating the waveform to include a component that allows for contactless activation of the ICBN. This modulation could occur by harvesting the existing power source of the ESU at specific time points within the duty cycle, or as an external power source that overlays the nerve-specific waveform onto the existing cautery duty cycle. In the first setup, the high-frequency AC current from the ESU would be rectified to a DC current, followed by a voltage step down mechanism and filtering. A supercapacitor can serve as the charge storage mechanism, with the discharge timed by a MOSFET, 555 timer, or other pre-programmed timing component. In the second setup, an external power unit, rather than the ESU, can be the source of the nerve-specific stimulation waveform.

## 2. Design Overview

### 2.1 Block Diagram


Figure 3: Block Diagram

## 2.2 Power System Overview

### 2.2.1 High Voltage Stage

A single stage buck is infeasible to safely and efficiently step down a 2000V DC input to a 5V DC output. We use 2000V DC as this is the output of the electrosurgical unit (ESU). Because of this, we will be implementing a multi stage power conversion system. The high voltage stage will take the 2kV DC and invert it to create a 2kV DC output. This will go through a transformer that will then step it down to 100V AC. This 100V AC will then be sent to a full bridge rectifier and filtering circuitry.

### 2.2.2 Mid Voltage Stage

The Mid Voltage Stage contains the rectifier and filtering circuitry, as well as a final buck converter to do the final step down to 5V DC. This 100V AC input, once rectified and filtered, will output 100V DC that is then sent to a buck converter that will do the final step down to 5V DC.

### 2.2.3 Low Voltage Stage

The input being the 5V DC from the mid-voltage stage, a supercapacitor can serve as the charge storage mechanism that is connected to a power mosfet. (This part of the circuit design has been simulated to be working besides the microcontroller input by the Neuroguard med students already). A capacitor provides sufficient energy to deliver short, low-current pulses. The stored energy is selectively discharged through a resistor (simulating nerve tissue) via an N-channel MOSFET, whose gate is driven by a 5V pulse signal from the microcontroller. When the gate receives a high signal, the MOSFET turns on, allowing the capacitor to release its energy as a precise stimulation pulse across the load.

### 2.2.4 Timer & Microcontroller Stage

The microcontroller detects when to alternate between the standard cautery function (pass-through) and the nerve stimulation waveform. The 555 timer IC as recommended in the Neuroguard med proposal controls when nerve stimulation is delivered to time the discharge of the capacitor. It also takes as input the 5V DC from the low voltage stage and uses it to deliver to detect the OFF periods of duty cycle of the ESU, which is when the nerve stimulation is allowed to be delivered. This PCB also provides the Cautery Tool Monitoring. This will output a signal to the mosfet driver that when high (5V), will turn MOSFET turns on, allowing the capacitor in the low voltage stage to release its energy as a precise stimulation pulse across the load.

## 2.3 Subsystem Requirements

### 2.3.1 High Voltage Stage

Power supply can successfully output 100V AC 5% tolerance. The entire apparatus is safe to use under medical criteria.

### 2.3.2 Mid Voltage Stage

Power supply can successfully output 5V DC 5% tolerance at 100mA 5% tolerance with voltage ripple less than 10% ( Output supply maximum ripple is from 4.5V to 5.5V, DC output is maintained from 4.75V to 5.25V). The entire apparatus is safe to use under medical criteria.

### 2.3.3 Low Voltage Stage

When the Mosfet receives a high signal, the MOSFET turns on, allowing the capacitor to release its energy as a precise stimulation pulse across the load is measured to be 0.1V at 50 Hz - 1 kHz. The waveform generated during the OFF period is still the ESU source.

### 2.3.4 Timer & Microcontroller Stage

The microcontroller, given a 5V input with a certain % Duty Cycle, is able to time when nerve stimulation occurs. The microcontroller must output 5V to the Mosfet Driver during the OFF portion of the Duty Cycle, and according to the 555 timer.

## 2.4 Risk Analysis

Significant considerations must be taken on the PCB layout and design for this power system. High voltage DC will require larger trace tolerances and specialized PCB dielectric to prevent arcing between traces. This entire apparatus must then be placed into an insulating chamber for improved safety. While buck converters are generally the most efficient method to step down DC voltages, because of the large jump from input voltage to output voltage required (100V DC to 5 V DC), efficiency will be closer to ~50% depending on the specific buck converter chosen. Thermal considerations are incredibly important so the buck converter does not overheat and shut down. The final large consideration is EMI filtering from the buck converter and Inverter sub systems. The DC power supply NeuroGuard will receive is incredibly sensitive to backpropagated conducted EMI. Significant filtering will need to be in place in order to ensure that this does not disrupt the cautery power supply.

The figure below shows the feasibility of the low voltage stage, as it shows the output of the nerve stimulation generation by the Neuroguard medical team with their proof of concept circuit.



Figure 4: Circuit Diagram and Simulation Output from the IEEE abstract [1].

## 3 Ethics & Safety

To make sure our group is working on our project safely and effectively, we will follow the IEEE

Code of Ethics that was adopted by the IEEE Board of Directors in 2020[2]. We understand that

technologies affect the quality of life around the world and we must work with a high ethical

standard as a professional team. Some of the most important, but not the only, ethics to follow

for our team are:

### 1. Seek, accept, and offer honest criticism of technical work, acknowledge and correct

errors, be honest, and realistic in stating claims or estimates based on available data

[2].

### 2. Treat all persons fairly and with respect, to avoid harassment or discrimination, and

to avoid injuring others [2].

3. Work to improve our technical competence but consider our qualification from

training or experience and disclose notable limitations [2].

To ensure safety in our design and following all regulations, we will take a number of

precautions to minimize danger in development and operation of our device. Because we will be

dealing with high voltage, possibly of 2000 Volts if connected to the hospital supply, it is important to make sure all components included in our design can withstand these voltage levels,

even after step-down converters are included. Also, we will make sure that all devices, such as

microcontrollers, and software follow relevant licensing requirements.

## 4 References

1) M. Singhal, K. Kiunga, N. Kelhofer, P. Dullur, N. Chigullapally, S. Pappu, and M. L.

Oelze, “Expanding the Scope of Intraoperative Neuromonitoring with Nerve-Specific

Stimulatory Waveform Design,” Carle Illinois College of Medicine and Department of

Electrical and Computer Engineering, University of Illinois Urbana-Champaign, Urbana,

IL, USA.

2) IEEE. “”IEEE Code of Ethics”.” (2016), [Online]. Available: https://www.ieee.org/

about/corporate/governance/p7-8.html (visited on 09/19/2025).

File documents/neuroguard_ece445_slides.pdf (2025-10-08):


### Cutting Edge Precision without Cutting Nerves

# NeuroGuard

ECE 445 Senior Design Course Launch, 8/26/25

Our Team; Suguna Pappu, MD, PhD Carle Health, Neurosurgeon; Michael Oelze, PhD UIUC Electrical Engineering; Victor Stams, MD Carle Health, Plastic surgeon; Clinical Advisors; Yuan Yang, PhD UIUC Bioengineering; Arijit Banerjee, PhD UIUC Electrical Engineering; Engineering Advisors; Meenakshi Singhal CIMED M2 ms189@illinois.edu; Nicolas Kelhofer CIMED M2 nck7@illinois.edu; Prateek Dullur CIMED M2 pdullur2@illinois.edu; Nikita Chigullapally CIMED M2 nikitc3@illinois.edu; Kathure Kiunga Undergraduate skiunga2@illinois.edu

Nerve Injury rate with mastectomy; Over 100,000/year in US; ICBN

Statistics from University of Michigan Health
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

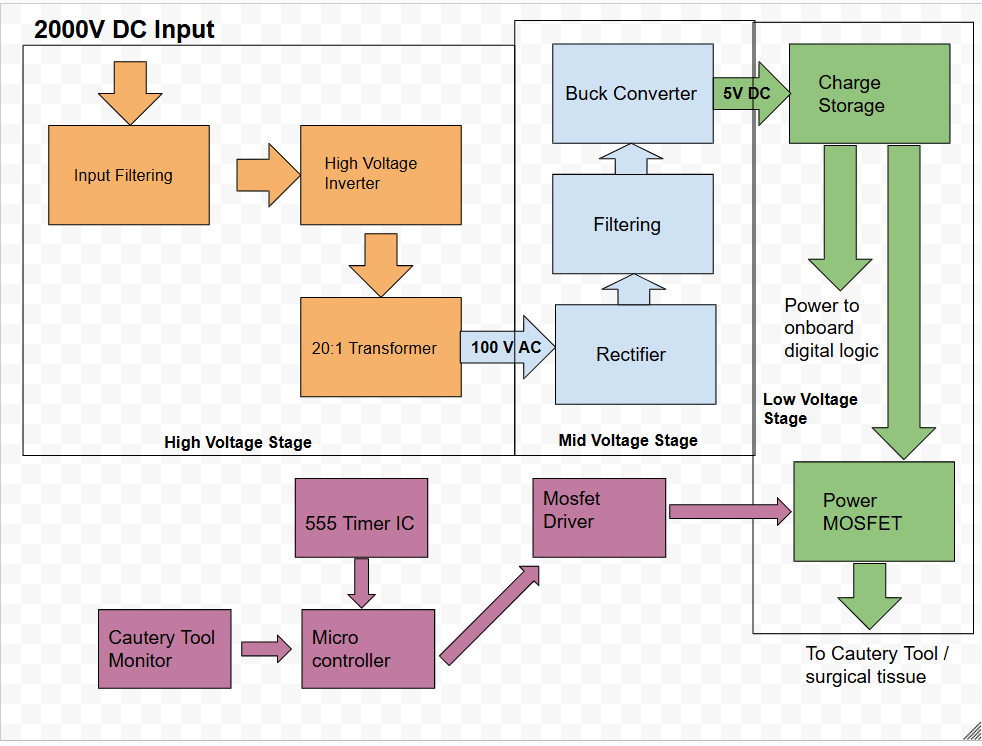
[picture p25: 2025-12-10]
Aidan Moran/Documents/Screenshot 2025-09-19 131524.png

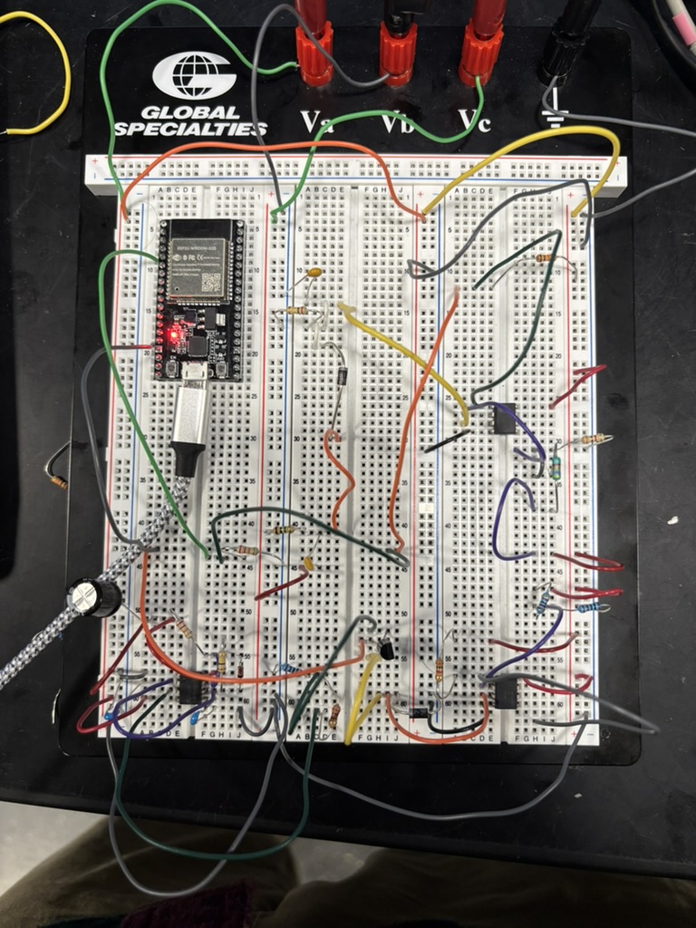
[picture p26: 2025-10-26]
ECU_monitor_V2/Breadboard_ecu_V2.jpeg

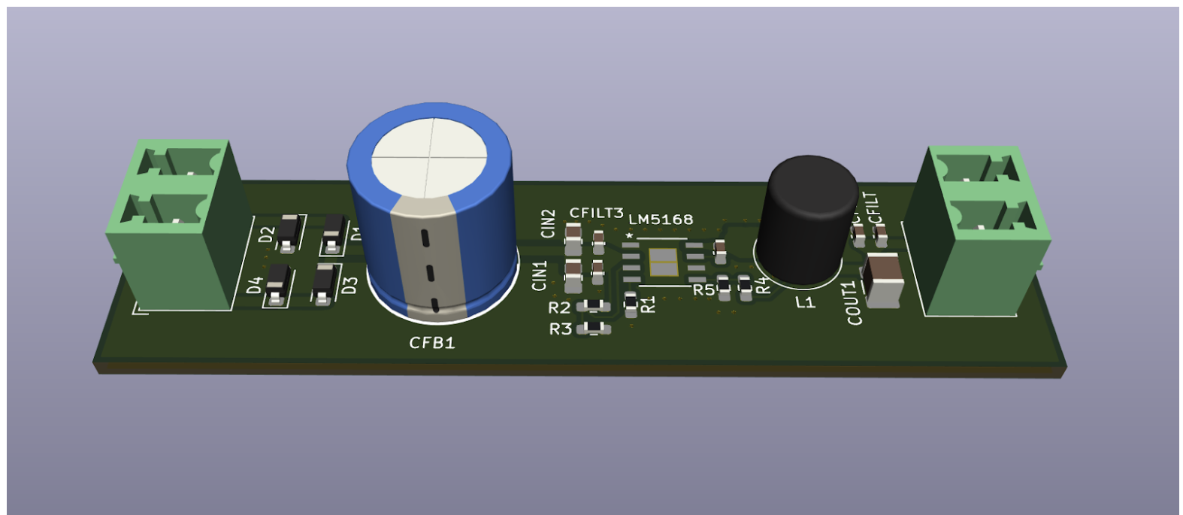
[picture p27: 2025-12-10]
Aidan Moran/Documents/Screenshot 2025-11-05 185239.png

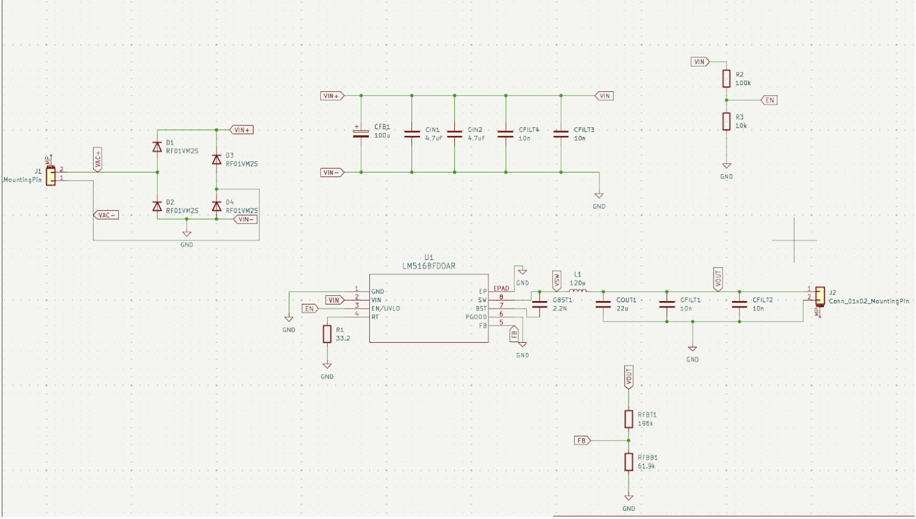
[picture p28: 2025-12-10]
Aidan Moran/Documents/Screenshot 2025-11-05 185218.png

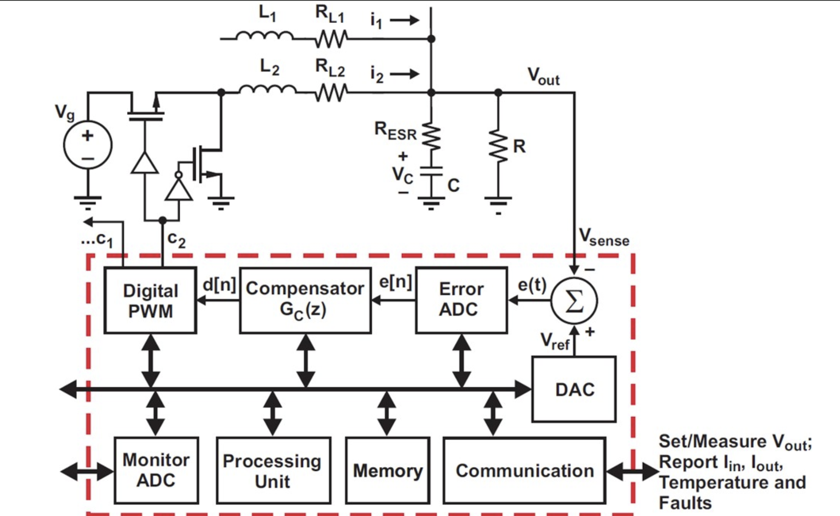
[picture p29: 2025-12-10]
Aidan Moran/Documents/Screenshot 2025-11-03 135019.png

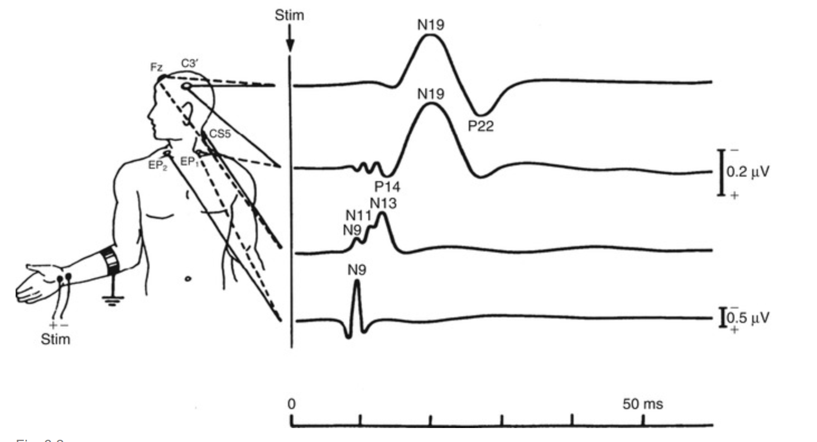
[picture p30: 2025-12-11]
Aidan Moran/Documents/Screenshot 2025-12-08 174535.png

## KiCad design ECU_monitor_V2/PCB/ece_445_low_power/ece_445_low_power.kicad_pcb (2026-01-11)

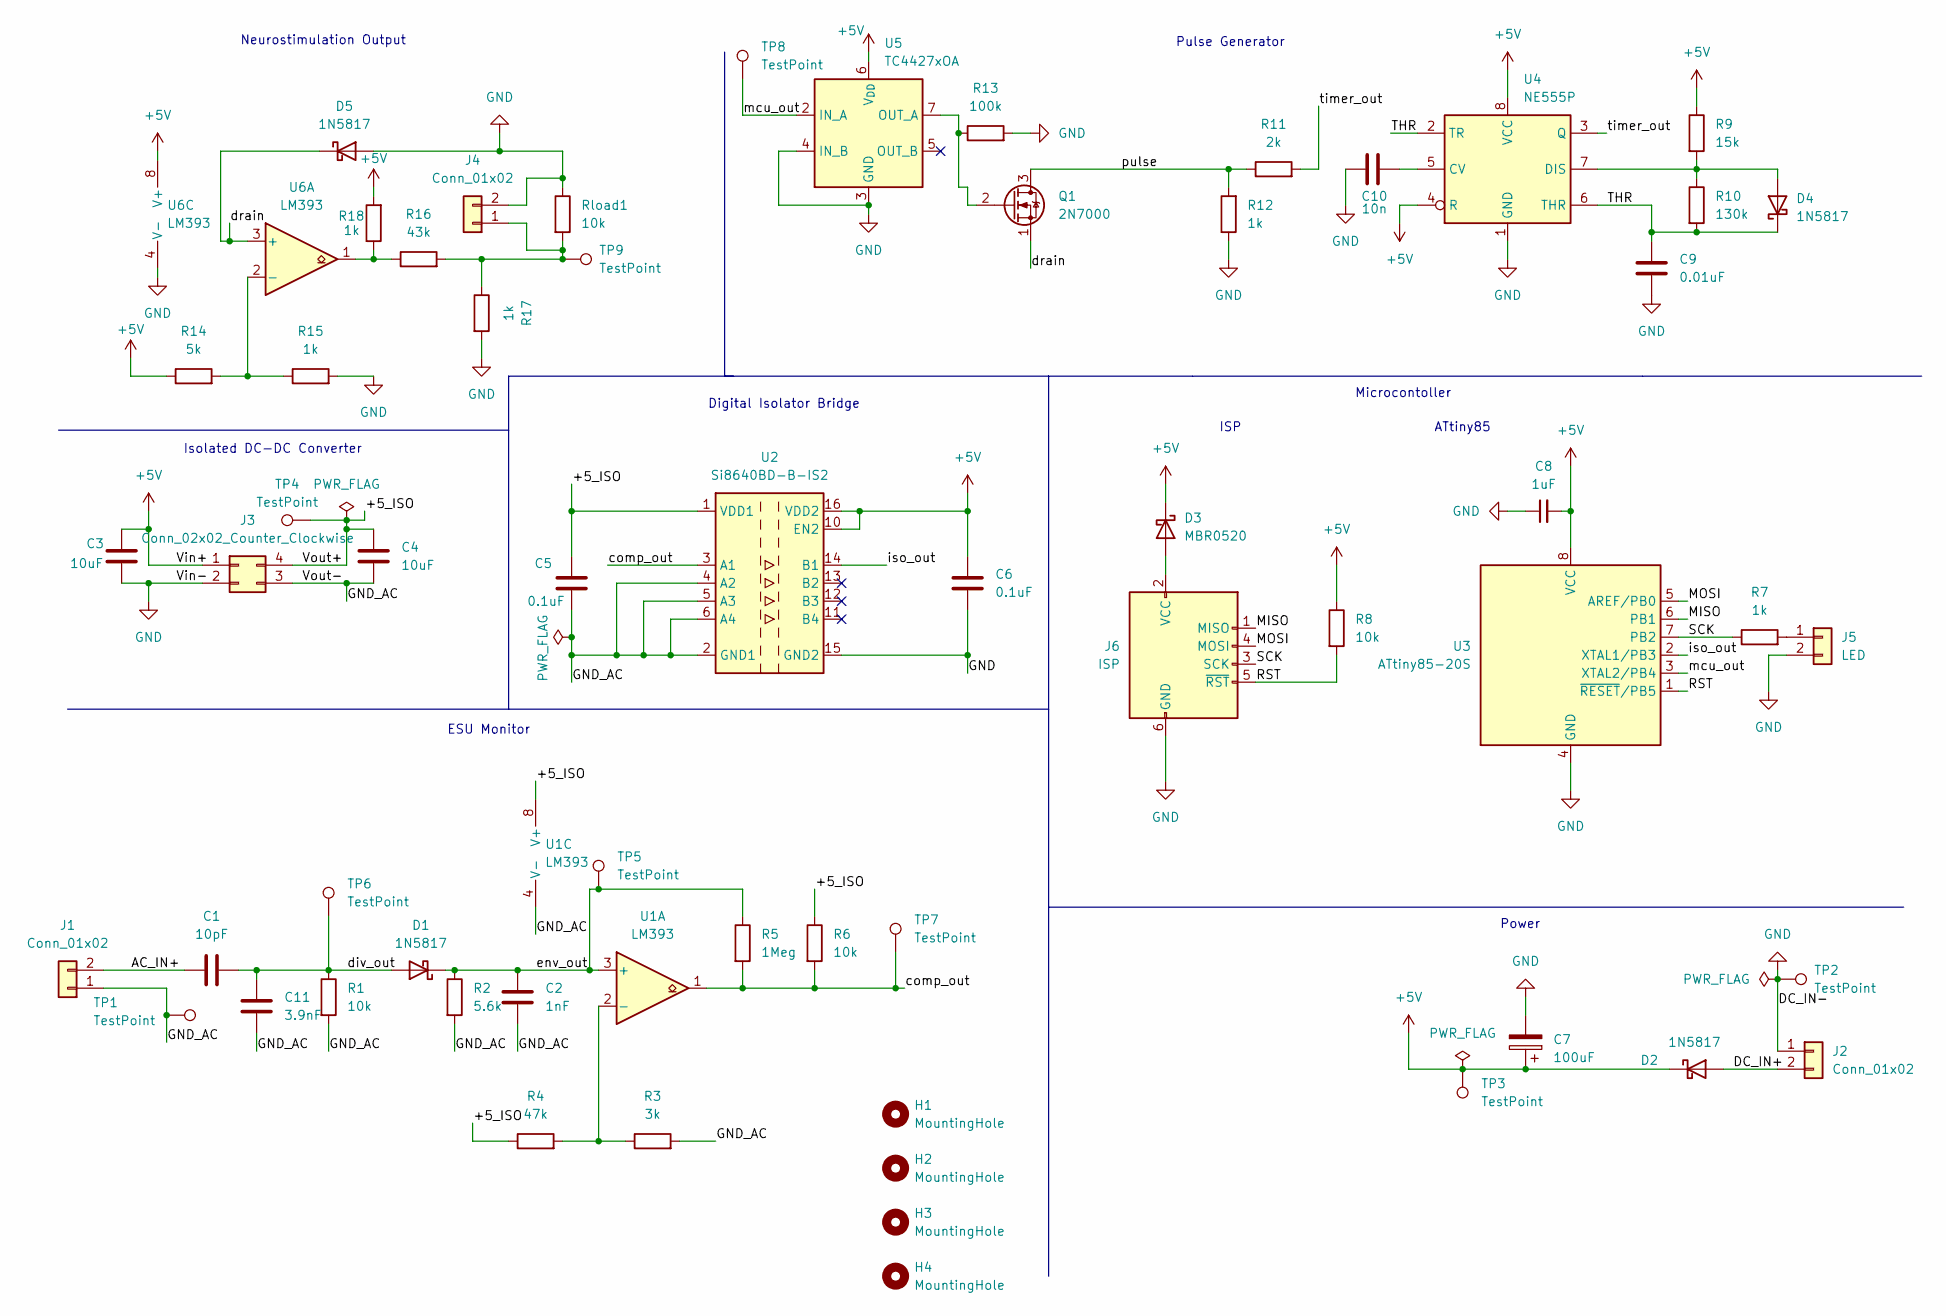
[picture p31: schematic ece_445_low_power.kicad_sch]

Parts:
C1: 10pF; C_Disc_D4.7mm_W2.5mm_P5.00mm
C2: 1nF; C_Disc_D4.7mm_W2.5mm_P5.00mm
C3, C4: 10uF; C_Disc_D4.7mm_W2.5mm_P5.00mm
C5, C6: 0.1uF; C_Disc_D4.7mm_W2.5mm_P5.00mm
C7: 100uF; C_Disc_D4.7mm_W2.5mm_P5.00mm
C8: 1uF; C_Disc_D4.7mm_W2.5mm_P5.00mm
C9: 0.01uF; C_Disc_D4.7mm_W2.5mm_P5.00mm
C10: 10n; C_Disc_D4.7mm_W2.5mm_P5.00mm
C11: 3.9nF; C_Disc_D4.7mm_W2.5mm_P5.00mm
D1, D2, D4, D5: 1N5817; D_DO-41_SOD81_P10.16mm_Horizontal
D3: MBR0520; D_SOD-123
H1, H2, H3, H4: MountingHole; MountingHole_3.2mm_M3
J1, J2, J4: Conn_01x02; PinHeader_1x02_P2.54mm_Vertical
J3: Conn_02x02_Counter_Clockwise; PinHeader_1x04_P2.54mm_Vertical
J5: LED; Molex_KK-254_AE-6410-02A_1x02_P2.54mm_Vertical
J6: ISP; IDC-Header_2x03_P2.54mm_Vertical
Q1: 2N7000; TO-92_Inline
R1, R6, R8: 10k; R_Axial_DIN0207_L6.3mm_D2.5mm_P10.16mm_Horizontal
R2: 5.6k; R_Axial_DIN0207_L6.3mm_D2.5mm_P10.16mm_Horizontal
R3: 3k; R_Axial_DIN0207_L6.3mm_D2.5mm_P10.16mm_Horizontal
R4: 47k; R_Axial_DIN0207_L6.3mm_D2.5mm_P10.16mm_Horizontal
R5: 1Meg; R_Axial_DIN0207_L6.3mm_D2.5mm_P10.16mm_Horizontal
R7, R12, R15, R17, R18: 1k; R_Axial_DIN0207_L6.3mm_D2.5mm_P10.16mm_Horizontal
R9: 15k; R_Axial_DIN0207_L6.3mm_D2.5mm_P10.16mm_Horizontal
R10: 130k; R_Axial_DIN0207_L6.3mm_D2.5mm_P10.16mm_Horizontal
R11: 2k; R_Axial_DIN0207_L6.3mm_D2.5mm_P10.16mm_Horizontal
R13: 100k; R_Axial_DIN0207_L6.3mm_D2.5mm_P10.16mm_Horizontal
R14: 5k; R_Axial_DIN0207_L6.3mm_D2.5mm_P10.16mm_Horizontal
R16: 43k; R_Axial_DIN0207_L6.3mm_D2.5mm_P10.16mm_Horizontal
Rload1: 10k; R_Axial_DIN0207_L6.3mm_D2.5mm_P10.16mm_Horizontal
TP1, TP2, TP3, TP4, TP5, TP6, TP7, TP8, TP9: TestPoint; TestPoint_Pad_D1.5mm
U1, U6: LM393; DIP-8_W7.62mm
U2: Si8640BD-B-IS2; SOIC-16W_7.5x10.3mm_P1.27mm
U3: ATtiny85-20S; SOIC-8_5.3x5.3mm_P1.27mm
U4: NE555P; DIP-8_W7.62mm
U5: TC4427xOA; SOIC-8_3.9x4.9mm_P1.27mm

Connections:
+5V: C3.2, C6.1, C7.1, C8.2, D2.1 (K), D3.1 (K), J3.1, R8.1, R9.1, R14.1, R18.2, TP3.1, U2.10 (EN2), U2.16 (VDD2), U3.8 (VCC), U4.4 (R), U4.8 (VCC), U5.6 (V_{DD}), U6.8 (V+)
/+5_ISO: C4.2, C5.1, J3.4, R4.1, R6.1, TP4.1, U1.8 (V+), U2.1 (VDD1)
/AC_IN+: C1.1, J1.2
/DC_IN+: D2.2 (A), J2.2
/GND_AC: C2.2, C4.1, C5.2, C11.1, J1.1, J3.3, R1.2, R2.2, R3.2, TP1.1, U1.4 (V-), U2.2 (GND1), U2.4 (A2), U2.5 (A3), U2.6 (A4), U2.8 (GND1)
/MISO: J6.1 (MISO), U3.6 (PB1)
/MOSI: J6.4 (MOSI), U3.5 (AREF/PB0)
/RST: J6.5 (~RST), R8.2, U3.1 (~RESET/PB5)
/SCK: J6.3 (SCK), R7.1, U3.7 (PB2)
/THR: C9.1, D4.1 (K), R10.2, U4.2 (TR), U4.6 (THR)
/comp_out: R5.2, R6.2, TP7.1, U1.1, U2.3 (A1)
/div_out: C1.2, C11.2, D1.2 (A), R1.1, TP6.1
/drain: D5.1 (K), Q1.1 (S), U6.3 (+)
/env_out: C2.1, D1.1 (K), R2.1, R5.1, TP5.1, U1.3 (+)
/iso_out: U2.14 (B1), U3.2 (XTAL1/PB3)
/mcu_out: TP8.1, U3.3 (XTAL2/PB4), U5.2 (IN_A)
/pulse: Q1.3 (D), R11.1, R12.2
/timer_out: R11.2, U4.3 (Q)
GND: C3.1, C6.2, C7.2, C8.1, C9.2, C10.1, D5.2 (A), J2.1, J3.2, J4.2, J5.2, J6.6 (GND), R12.1, R13.2, R15.2, R17.2, Rload1.1, TP2.1, U2.9 (GND2), U2.15 (GND2), U3.4 (GND), U4.1 (GND), U5.3 (GND), U5.4 (IN_B), U6.4 (V-)
unnamed: D3.2 (A), J6.2 (VCC)
unnamed: D4.2 (A), R9.2, R10.1, U4.7 (DIS)
unnamed: J4.1, R16.2, R17.1, Rload1.2, TP9.1
unnamed: J5.1, R7.2
unnamed: Q1.2 (G), R13.1, U5.7 (OUT_A)
unnamed: R16.1, R18.1, U6.1
unnamed: R3.1, R4.2, U1.2 (-)
unnamed: C10.2, U4.5 (CV)
unnamed: R14.2, R15.1, U6.2 (-)

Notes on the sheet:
ESU Monitor
Pulse Generator
Neurostimulation Output
Digital Isolator Bridge
Isolated DC-DC Converter
Microcontoller
ISP
Power
ATtiny85

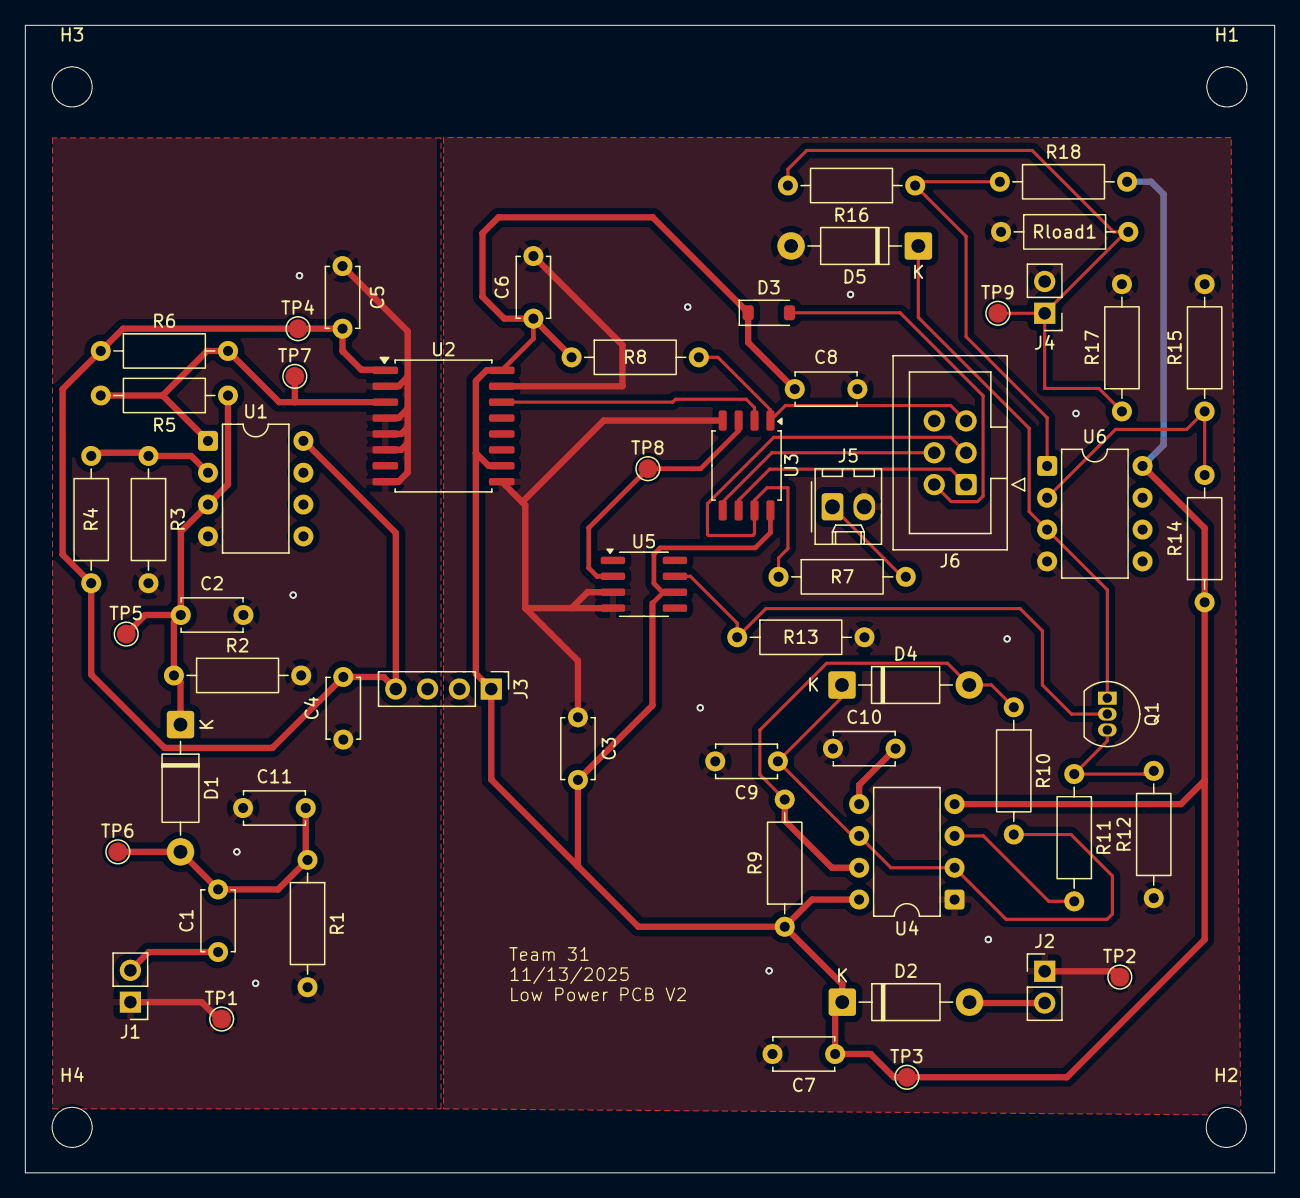
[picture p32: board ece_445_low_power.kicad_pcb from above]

Board: 2 copper layers, 99.7 x 91.6 mm, 61 parts (0 on the bottom side), 28 nets.

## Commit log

2025-10-08 Adding Power folder
2025-10-13 Include nerve stimulation circuit with mosfet
2025-10-17 Adding low_power pcb
    [ece_445_low_power-B_Cu.gbl, ece_445_low_power-B_Mask.gbs, ece_445_low_power-B_Paste.gbp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]
2025-11-20 Adding stripped PCB to github
    [ece_445_low_power_stripped-B_Cu.gbl, ece_445_low_power_stripped-B_Mask.gbs, ece_445_low_power_stripped-B_Paste.gbp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]
2025-12-11 Document testing integration with low voltage stage
    Added a section on testing integration with the low voltage stage, detailing the setup and observations during testing.
2026-01-11 Updated Low Power PCB, added missing 1k resistor to +5V in output
    [ece_445_low_power-B_Cu.gbl, ece_445_low_power-B_Mask.gbs, ece_445_low_power-B_Paste.gbp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]
2026-01-11 cleanup of ECUMonitor to remove extra wires
